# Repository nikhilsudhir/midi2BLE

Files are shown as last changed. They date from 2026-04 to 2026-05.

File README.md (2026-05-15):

<div align="center">

# midi2BLE

**Custom wireless MIDI adapter — ESP32-S3, LiPo powered, custom PCB**



[]()


A custom, battery-powered BLE MIDI adapter with a bespoke PCB and 3D-printed enclosure. Bridges a USB MIDI keyboard to a Mac over Bluetooth LE, eliminating the cable between instrument and computer.

[**View project page →**](https://nikhilsudhir.github.io/projects/midi2BT.html)

</div>

---

## Signal flow

<div align="center">

| **USB MIDI Keyboard** | | **ESP32-S3** | | **macOS** | | **DAW** |
|:---:|:---:|:---:|:---:|:---:|:---:|:---:|
| *(e.g. MPK Mini III)* | `── USB ──►` | *midi2BLE firmware* | `── BLE MIDI ──►` | *Audio MIDI Setup* | `──►` | *FL Studio* |

</div>

---

## Features

| | |
|---|---|
| **Wireless mode** | ESP32-S3 acts as USB host; MIDI data forwarded over BLE to macOS |
| **Passthrough mode** | Keyboard connected directly to upstream USB-C via hardware switch — ESP32 out of data path |
| **USB MIDI host** | Enumerates any class-compliant USB MIDI controller — no driver needed |
| **BLE MIDI peripheral** | Apple BLE MIDI spec, appears as a native MIDI port in Audio MIDI Setup |
| **MIDI panic** | On USB disconnect, sends Note Off + CC 123/120 for every active note on all 16 channels |
| **Auto-advertising** | Restarts BLE advertising automatically on every disconnect or reboot |
| **OLED display** | SPI-connected display shows mode, BLE status, battery %, and estimated runtime |
| **Battery management** | LiPo charge, power-path control, and ADC-based battery sense |

---

## Hardware

### Electronics

| Component | Part | Role |
|---|---|---|
| MCU / BLE | ESP32-S3-WROOM-1-N8 | Application processor, USB host, BLE MIDI |
| LiPo charger | BQ24079RGTT | 1-cell USB-C LiPo charging with power path |
| Buck regulator | TPS62162DSG | 3.3 V system rail |
| Boost converter | TLV61047DDC | 5 V VBUS supply for keyboard (wireless mode) |
| Power mux | TPS2116DRL | Battery / USB-C power-path switching |
| USB switch | TS3USB30EDGSR | Routes keyboard D+/D− to ESP32 or upstream port |
| USB ESD | PRTR5V0U2X | ESD protection on USB lines |
| Display | SPI OLED | Mode, connection status, battery info |

> Tested with an **Akai MPK Mini III**. Any USB class-compliant MIDI device should work.

### PCB

| | |
|---|---|
| Dimensions | 100 × 40 mm |
| Layers | 4 |
| Stackup | JLCPCB JLC04161H-7628 |
| Surface finish | HASL |
| Soldermask | Black |
| Mounting holes | M2.5 |

---

## Repository structure

- `main/` — Firmware (ESP-IDF / C) — see [main/README.md](main/README.md)
- `hardware/`
  - `ecad/` — KiCad schematic & PCB layout — see [hardware/ecad/README.md](hardware/ecad/README.md)
  - `mcad/` — Fusion 360 enclosure — see [hardware/mcad/README.md](hardware/mcad/README.md)
- `CMakeLists.txt`
- `sdkconfig.defaults`

---

## Build status

| Component | Status |
|---|---|
| Firmware | ✅ Complete |
| Schematic | ✅ Complete |
| PCB layout | ✅ Complete |
| Enclosure | ✅ Complete |

---

<div align="center">

[nikhilsudhir.github.io](https://nikhilsudhir.github.io/projects/midi2BLE.html)

</div>

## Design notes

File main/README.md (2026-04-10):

# Firmware

ESP32-S3 firmware for the midi2BLE adapter. Written in C using ESP-IDF v6.0 and NimBLE.

---

## Architecture

Three tasks run concurrently under FreeRTOS:

| Task | Priority | Description |
|---|---|---|
| `usb_host` | 2 | Runs the USB host library event loop |
| `class` | 3 | USB class driver — enumerates devices, handles MIDI transfers |
| NimBLE host | — | Managed internally by NimBLE port |

`app_main` initialises BLE, starts both tasks, then returns.

---

## File structure

```
main/
├── usb_host_lib_main.c     Entry point, USB host library task
├── class_driver.c          USB class driver, MIDI parsing, note tracking & panic
├── ble_midi.c              BLE MIDI peripheral, GATT service, advertising
├── ble_midi.h              Module interface
├── idf_component.yml       Component dependencies
└── CMakeLists.txt
```

---

## Module overview

### `usb_host_lib_main.c`
Entry point. Initialises the BLE MIDI peripheral, installs the USB host library, and spawns the USB host and class driver tasks.

### `class_driver.c`
Registers as a USB host client and waits for MIDI devices to connect. On connection it claims the MIDI Streaming interface and begins bulk IN transfers. Incoming 4-byte USB MIDI event packets are parsed, forwarded over BLE, and tracked for active note state. On disconnect, fires a MIDI panic before releasing the device.

### `ble_midi.c` / `ble_midi.h`
NimBLE peripheral implementing the Apple BLE MIDI spec. Exposes two functions:

```c
void ble_midi_init(void);
void ble_midi_send(const uint8_t *midi_bytes, int len);
```

Advertising starts automatically on boot and restarts on every disconnect.

---

## MIDI panic

If a USB MIDI device is unplugged while notes are held, the host would otherwise receive no Note Off and notes would drone indefinitely. On every USB disconnect the firmware:

1. Sends Note Off for every tracked active note
2. Sends CC 123 (All Notes Off) on all 16 channels
3. Sends CC 120 (All Sound Off) on all 16 channels

---

## Building

Requires [ESP-IDF v6.0](https://docs.espressif.com/projects/esp-idf/en/v6.0/esp32s3/get-started/).

```bash
idf.py build
idf.py -p PORT flash monitor
```

Target is fixed to `esp32s3` via `sdkconfig.defaults`.

---

## Dependencies

| Component | Source |
|---|---|
| `espressif/usb ^1.0.0` | [ESP-IDF Component Registry](https://components.espressif.com/components/espressif/usb) |
| NimBLE | Bundled with ESP-IDF (`CONFIG_BT_NIMBLE_ENABLED`) |

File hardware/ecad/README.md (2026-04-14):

# midi2BLE

## Overview

This device is a portable USB-to-BLE MIDI bridge designed to interface with USB MIDI controllers such as the Akai MPK Mini III.

It supports two user-selectable modes:

* Wireless BLE MIDI operation
* Wired USB passthrough operation

The device is battery powered with USB-C charging and includes an onboard OLED display for status and battery information.

---

## Operating Modes

### 1. Wireless Mode

In this mode, the device acts as a BLE MIDI bridge.

#### Behavior

* ESP32-S3 operates as a USB host
* MIDI data is read from the keyboard and transmitted via BLE
* Device is powered from internal LiPo battery
* OLED displays:

  * battery percentage
  * estimated runtime
  * BLE connection status
  * keyboard connection status

#### Power

* Battery supplies system power
* Optional charging via USB-C

---

### 2. Passthrough Mode

In this mode, the device behaves as a direct USB cable between the keyboard and a computer.

#### Behavior

* Keyboard is directly connected to upstream USB-C port via hardware switching
* ESP32 is not part of the USB data path
* BLE functionality is disabled
* OLED remains active and displays:

  * "WIRED MODE"
  * charging status
  * battery percentage

#### Power

* System is powered from upstream USB-C
* Battery does NOT power the system
* Battery may still be charged

---

## Mode Selection

* A physical switch selects between:

  * WIRELESS
  * WIRED
* The switch is authoritative
* Mode switching is NOT live
* Device must be restarted after changing modes

---

## Ports

### Upstream USB-C Port

* Used for:

  * charging the device
  * connecting to a computer in passthrough mode
* Supplies system power when connected

### Keyboard USB-C Port

* Used to connect the MIDI controller
* Behavior depends on mode:

  * Wireless: connected to ESP32 USB host
  * Passthrough: connected directly to upstream USB-C

---

## Power Architecture

* 1-cell LiPo battery
* USB-C charging input
* Power-path design allows:

  * operation while charging
  * seamless transition between power sources

### Power Priorities

#### Wireless Mode

1. Battery powers system
2. USB-C supplements or charges battery

#### Passthrough Mode

1. Upstream USB-C powers system
2. Battery is isolated from load
3. Battery may still charge

---

## USB Routing

### Wireless Mode

* Keyboard D+/D- connected to ESP32 USB host

### Passthrough Mode

* Keyboard D+/D- connected directly to upstream USB-C port

This is implemented using a USB 2.0 switch/multiplexer.

---

## Keyboard Power (VBUS)

### Wireless Mode

* Supplied by internal 5V boost converter

### Passthrough Mode

* Supplied directly from upstream USB-C VBUS

---

## Display (OLED)

* SPI-connected monochrome OLED display
* Displays:

  * battery percentage
  * estimated runtime
  * current mode
  * connection status

---

## Firmware Behavior

### Wireless Mode

* USB host enabled
* BLE MIDI enabled
* MIDI data forwarded USB → BLE

### Passthrough Mode

* USB host disabled
* BLE disabled
* ESP32 used only for UI/status

---

## V1 Scope

### Included

* BLE MIDI output
* USB passthrough
* battery operation
* USB-C charging
* OLED display
* manual mode switch

### Excluded

* custom RF protocols
* MIDI remapping
* display UI complexity
* automatic mode switching
* USB hub functionality

---

## Hardware Design

The schematic and PCB layout are both complete. The design is implemented in **KiCad 10.0**.

| | |
|---|---|
| Revision | 1 |
| Schematic date | 2026-04-11 |
| PCB date | 2026-04-12 |

The schematic is split across seven sheets:

| Sheet | Description |
|---|---|
| Root | Top-level block diagram and inter-sheet connections |
| Power | LiPo charging, buck/boost regulation, and power-path control |
| ESP32_S3 | ESP32-S3-WROOM-1 module, decoupling, and GPIO assignments |
| USB Data | USB 2.0 data switching between keyboard and upstream port |
| VBUS Switching | 5V VBUS supply selection for the keyboard port |
| OLED UI | SPI OLED display and mode select switch |
| Battery Sense | Resistor divider and ADC input for battery voltage measurement |

### Key ICs

| IC | Part | Function |
|---|---|---|
| U1 | ESP32-S3-WROOM-1 | Main MCU + Wi-Fi/BLE module |
| U2 | BQ24074RGTT | 1-cell LiPo charger |
| U3 | TPS62162DSG | 3.3 V synchronous buck regulator |
| U4 | TLV61047DDC | 5 V boost converter (keyboard VBUS in wireless mode) |
| U5 | TPS2116DRL | Dual-input power mux (battery vs. USB-C power path) |
| U6 | TS3USB30EDGSR | USB 2.0 high-speed switch (keyboard data routing) |
| U7 | PRTR5V0U2X | USB ESD protection |

### PCB

The PCB is laid out in KiCad. All components are placed and fully routed.

**Board dimensions:** 75 × 40mm  
**Thickness:** 1.6mm  
**Layers:** 4  

#### Stackup

| Layer | Type | Thickness | Material |
|---|---|---|---|
| F.Cu | Signal | 35µm | Copper |
| Dielectric 1 | Prepreg | 0.1mm | FR4 |
| In1.Cu | GND plane | 35µm | Copper |
| Dielectric 2 | Core | 1.24mm | FR4 |
| In2.Cu | 3.3V power plane | 35µm | Copper |
| Dielectric 3 | Prepreg | 0.1mm | FR4 |
| B.Cu | Signal | 35µm | Copper |

Inner layers are solid copper fills: In1 = GND, In2 = SYS_3V3.

**Test points:** TP1–TP6  
**Via size:** 0.45mm diameter, 0.2mm drill

---

## Summary

This V1 design prioritizes:

* simplicity
* reliability
* clear user control

The system uses a manual mode switch and hardware-level USB routing to ensure predictable behavior and robust operation.

**Current status:** Schematic and PCB layout complete. Ready for fabrication review.

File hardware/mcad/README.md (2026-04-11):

# MCAD — Enclosure Design

3D-printed enclosure for the midi2BLE hardware.

## Status

| Part | Status |
|---|---|
| Enclosure body | ✅ v1 designed, fitment tested against keyboard |
| USB-B cutout | ✅ Cutout included in v1 for keyboard USB-B port |
| Lid / cover | 🔧 Pending |
| PCB internal pocket | 🔧 Pending PCB dimensions from ECAD |

## Contents

- Enclosure body v1 — USB-B cutout, designed around reference keyboard model for fitment
- Lid / cover *(pending)*
- STL files for printing *(pending)*
- STEP files for reference *(pending)*

## Tools

- Fusion 360

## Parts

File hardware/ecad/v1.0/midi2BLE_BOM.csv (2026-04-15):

Id | Designator | Footprint | Quantity | Designation | Supplier and ref
1 | C1, C2, C3, C4, C10, C18 | C_0603_1608Metric | 6 | 10uF
2 | C5, C6, C7, C8, C9, C11, C12, C13, C14, C15, C16, C17, C19 | C_0402_1005Metric | 13 | 100nF
3 | D1, D2 | SOT-143 | 2 | PRTR5V0U2X
4 | J1 | USB_C_Receptacle_Amphenol_12401610E4-2A_CircularHoles | 1 | USB_C_Receptacle
5 | J2 | JST_PH_B2B-PH-K_1x02_P2.00mm_Vertical | 1 | Conn_01x02
6 | J4 | JST_EH_B7B-EH-A_1x07_P2.50mm_Vertical | 1 | Conn_01x07
7 | J6 | JST_PH_B4B-PH-K_1x04_P2.00mm_Vertical | 1 | Conn_01x04
8 | L1, L2 | L_1008_2520Metric | 2 | 2.2uH
9 | R1, R2 | C_0402_1005Metric | 2 | 5.1k
10 | R3 | C_0402_1005Metric | 1 | 590
11 | R4 | C_0402_1005Metric | 1 | 1k
12 | R5, R6, R7, R8, R9 | C_0402_1005Metric | 5 | 10k
13 | R10 | C_0402_1005Metric | 1 | 100
14 | R11 | C_0402_1005Metric | 1 | 220k
15 | R12, R13, R14 | C_0402_1005Metric | 3 | 100k
16 | SW1, SW2 | SW_SPST_B3U-1000P | 2 | SW_Push
17 | SW3 | SW_Slide_SPDT_Angled_CK_OS102011MA1Q | 1 | SW_SPDT
19 | U1 | VQFN-16-1EP_3x3mm_P0.5mm_EP1.68x1.68mm_ThermalVias | 1 | BQ24079RGTT
20 | U2 | WSON-8-1EP_2x2mm_P0.5mm_EP0.9x1.6mm_ThermalVias | 1 | TPS62162DSG
21 | U3 | SOT-23-5 | 1 | TLV61047DDC
22 | U4 | ESP32-S3-WROOM-1 | 1 | ESP32-S3-WROOM-1
23 | U5 | SOT-583-8 | 1 | TPS2116DRL
24 | U6 | TSSOP-10_3x3mm_P0.5mm | 1 | TS3USB30EDGSR

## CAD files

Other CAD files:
hardware/mcad/midi2BLE.f3d

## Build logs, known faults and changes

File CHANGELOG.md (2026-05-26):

# Changelog

All notable changes to this project are documented here.

---

## [Unreleased]

---

## [2.0.0] — 05/2026

### Changed — Power Section

#### U1 — Battery Charger
- Replaced BQ24079RGTT with BQ24075RGT
- Fixes SYSOFF floating issue — BQ24075 does not have a SYSOFF pin

#### U3 — 5V Boost Converter
- Replaced TLV61047DDC with MT3608 (SOT-23-6) + external SS14 Schottky diode
- FB divider: R_upper = 68kΩ, R_lower = 8.2kΩ → 5.0V output
- EN pin driven by MODE_SEL GPIO — boost disabled in passthrough mode

#### U2 — 3.3V Buck Regulator (TPS62162DSG, unchanged IC)
- EN fix: previously tied to U3 VIN causing circular startup dependency; now connected directly to U1_OUT
- FB fix: previously connected to SYS_3V3 (wrong); now tied to GND

#### Miscellaneous Power
- R5 removed — 10kΩ VBUS_IN to GND bleed resistor served no purpose

### Changed — USB Switching (U6 TS3USB30E, unchanged IC)
- OE pin: previously driven by MODE_SEL (disconnected switch in one mode); now tied directly to GND (switch always enabled)

### Changed — ESP32 GPIO Assignments
- OLED SPI reassigned from GPIO11/12 → GPIO35/36 (GPIO11/12 conflict with octal flash on N8R2 variant)
- MODE_SEL reassigned from GPIO0 → GPIO2 (GPIO0 is boot strapping pin)

---

## [1.0.0] — 04/2026

### Known Issues (reason for v2 redesign)
- SYSOFF pin on BQ24079 left floating — internally pulled HIGH through 5MΩ to VBAT, disabling battery output and charging entirely; board appeared completely dead
- U2 EN tied to U3 VIN causing circular startup dependency
- U2 FB incorrectly connected to SYS_3V3 instead of GND
- U6 OE driven by MODE_SEL instead of tied to GND, disconnecting USB switch in one mode
- OLED SPI on GPIO11/12 conflicting with octal flash on ESP32-S3-WROOM-1-N8R2
- MODE_SEL on GPIO0 (boot strapping pin) causing boot issues

### Added

#### ECAD
- 7-sheet KiCad schematic — ERC clean
- Full 4-layer PCB routing complete — DRC clean
- Board: 100×40mm, JLCPCB JLC04161H-7628 stackup
- Surface finish: HASL, black soldermask
- Mounting holes: M2.5

#### MCAD
- Enclosure body v1 designed in Fusion 360 — USB-C cutout for keyboard port, fitment verified against reference keyboard model
- Rudimentary reference keyboard model created to assist with clearance and alignment

---

## [0.4.1] — 04/2026

### Added
- Full USB device name on screen — reads both manufacturer and product strings from USB descriptor, word-wraps to second line if longer than 21 characters
- Battery monitor code complete — ADC oneshot on GPIO4 with curve/line fitting calibration, battery bar and percentage on display; pending physical wiring (100kΩ resistors)

### Fixed
- Display driver rewritten for SH1106 compatibility — switched from horizontal addressing mode (SSD1306 only) to page-by-page writes which work on both SH1106 and SSD1306
- Charge pump command corrected for SH1106 (0xAD, 0x8B)
- Mode switch moved from GPIO0 to GPIO2 to avoid conflict with ESP32-S3 boot pin
- Build errors resolved — wrong USB host function name (`usb_host_device_info`), unused static function ordering

### Changed
- Display rotated 180° via segment remap and COM scan direction commands
- All screen text centred

---

## [0.4.0] — 04/2026

### Added
- GPIO mode switch — HIGH = WIRELESS (BLE), LOW = PASSTHROUGH (wired); reads at boot with internal pull-up
- Mode change detection via NVS — shows restart screen and reboots cleanly when switch position changes
- SH1106 SPI OLED display driver (128×64) with built-in 5×7 bitmap font
- Status screens for both modes — BLE connection state, USB device name, MIDI activity indicator
- USB product and manufacturer strings read from device descriptor and shown on screen
- 1 Hz OLED update task
- `mode_manager`, `oled_display`, and `battery` modules added as separate files

### Changed
- NVS initialisation moved to `app_main` so all modules share one init
- `app_main` branches on mode — PASSTHROUGH skips BLE and USB host entirely

---

## [0.3.0] — 04/2026

### Added
- MIDI panic on USB disconnect — sends Note Off for all active notes, plus CC 123 (All Notes Off) and CC 120 (All Sound Off) on all 16 channels
- Active note tracking per channel to avoid duplicate Note Off messages
- BLE advertising restarts automatically on every disconnect

### Changed
- Cleaned up repository structure — removed devcontainer, tidied .gitignore, added LICENSE and README

---

## [0.2.0] — 04/2026

### Added
- Full BLE MIDI peripheral implementation (Apple BLE MIDI spec)
- NimBLE GATT service with correct service and characteristic UUIDs
- MIDI forwarding from USB to BLE with proper timestamp framing
- Akai MPK Mini III confirmed working end-to-end

---

## [0.1.0] — 03/2026

### Added
- ESP32-S3 running as USB MIDI host
- USB MIDI device enumeration and MIDI Streaming interface detection
- Raw MIDI data passthrough to serial monitor for verification

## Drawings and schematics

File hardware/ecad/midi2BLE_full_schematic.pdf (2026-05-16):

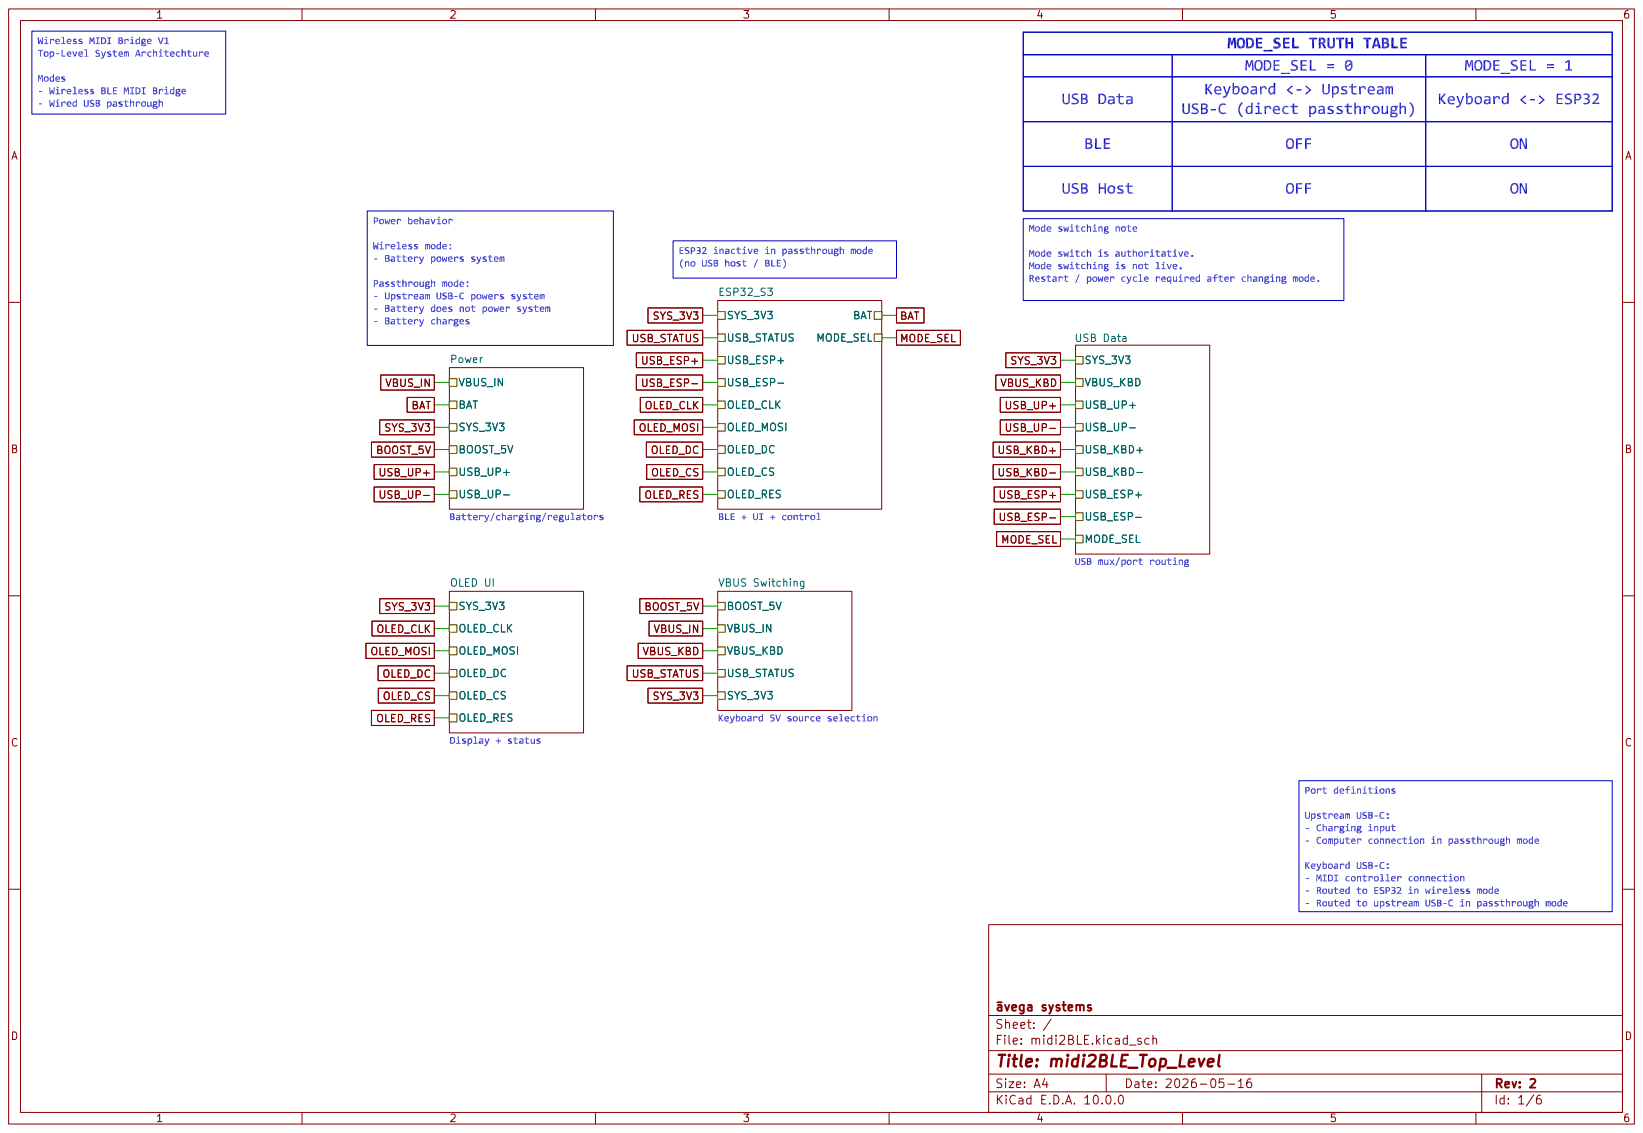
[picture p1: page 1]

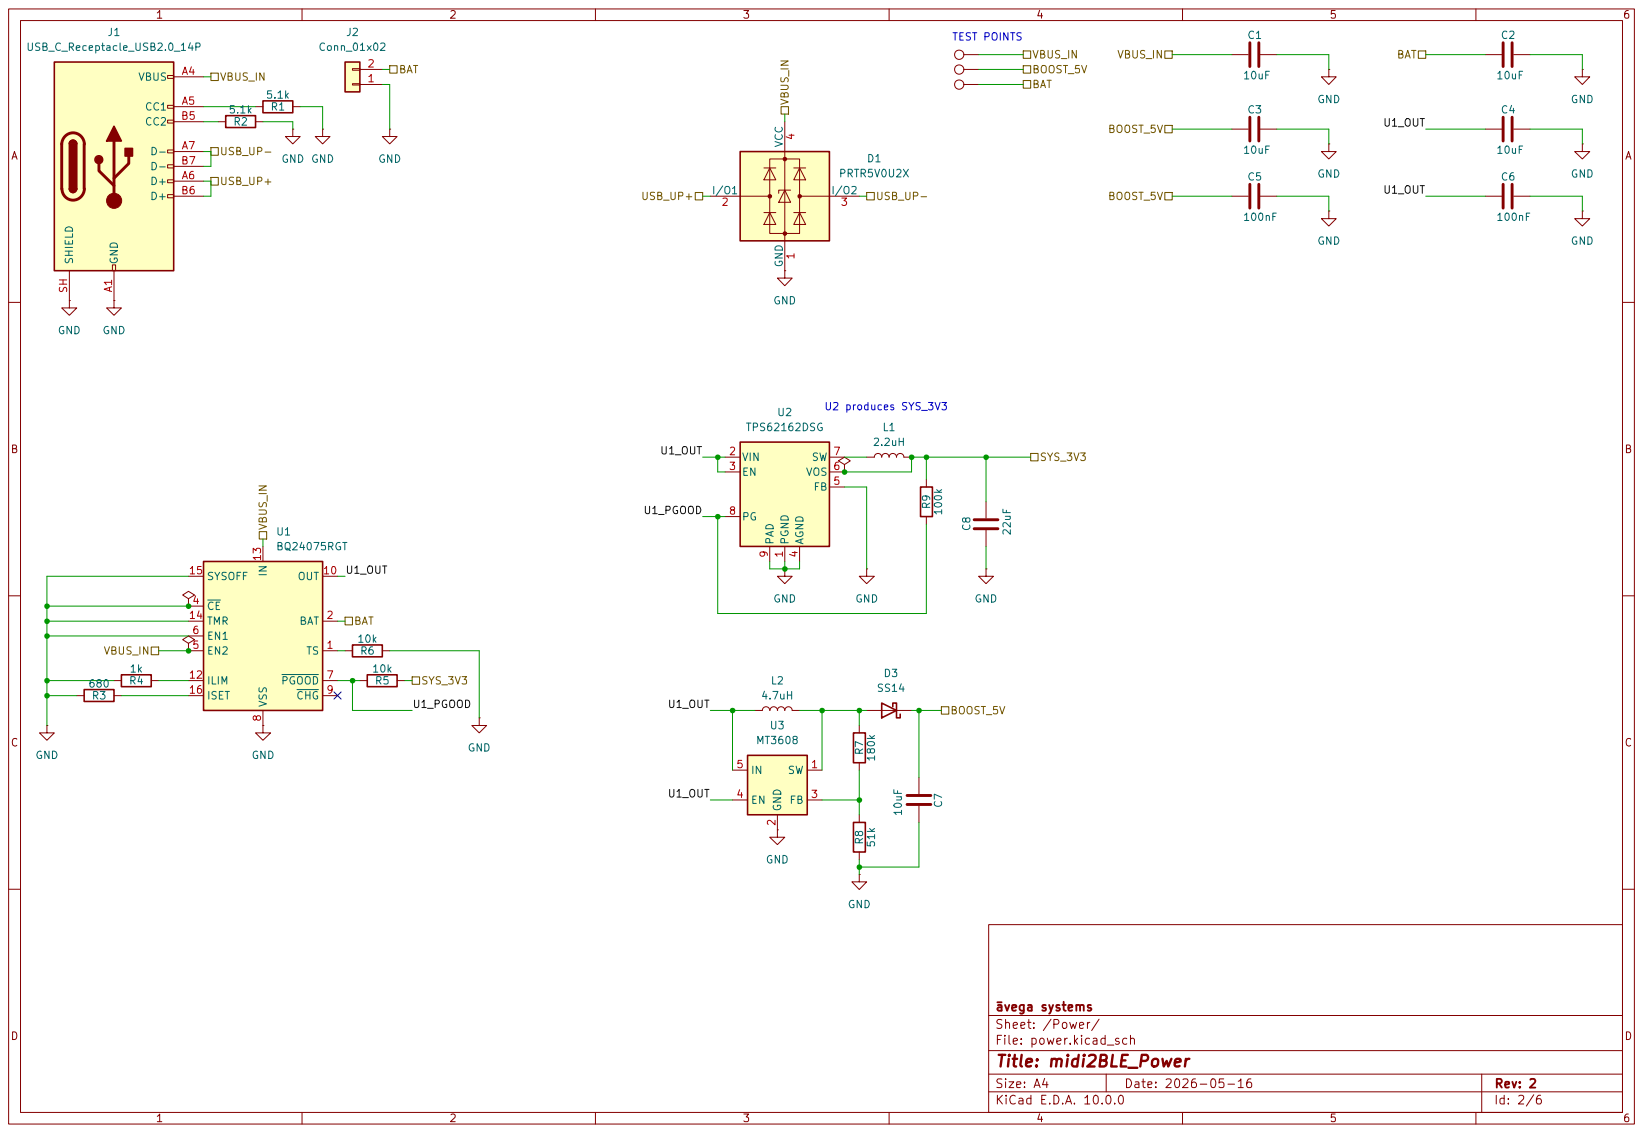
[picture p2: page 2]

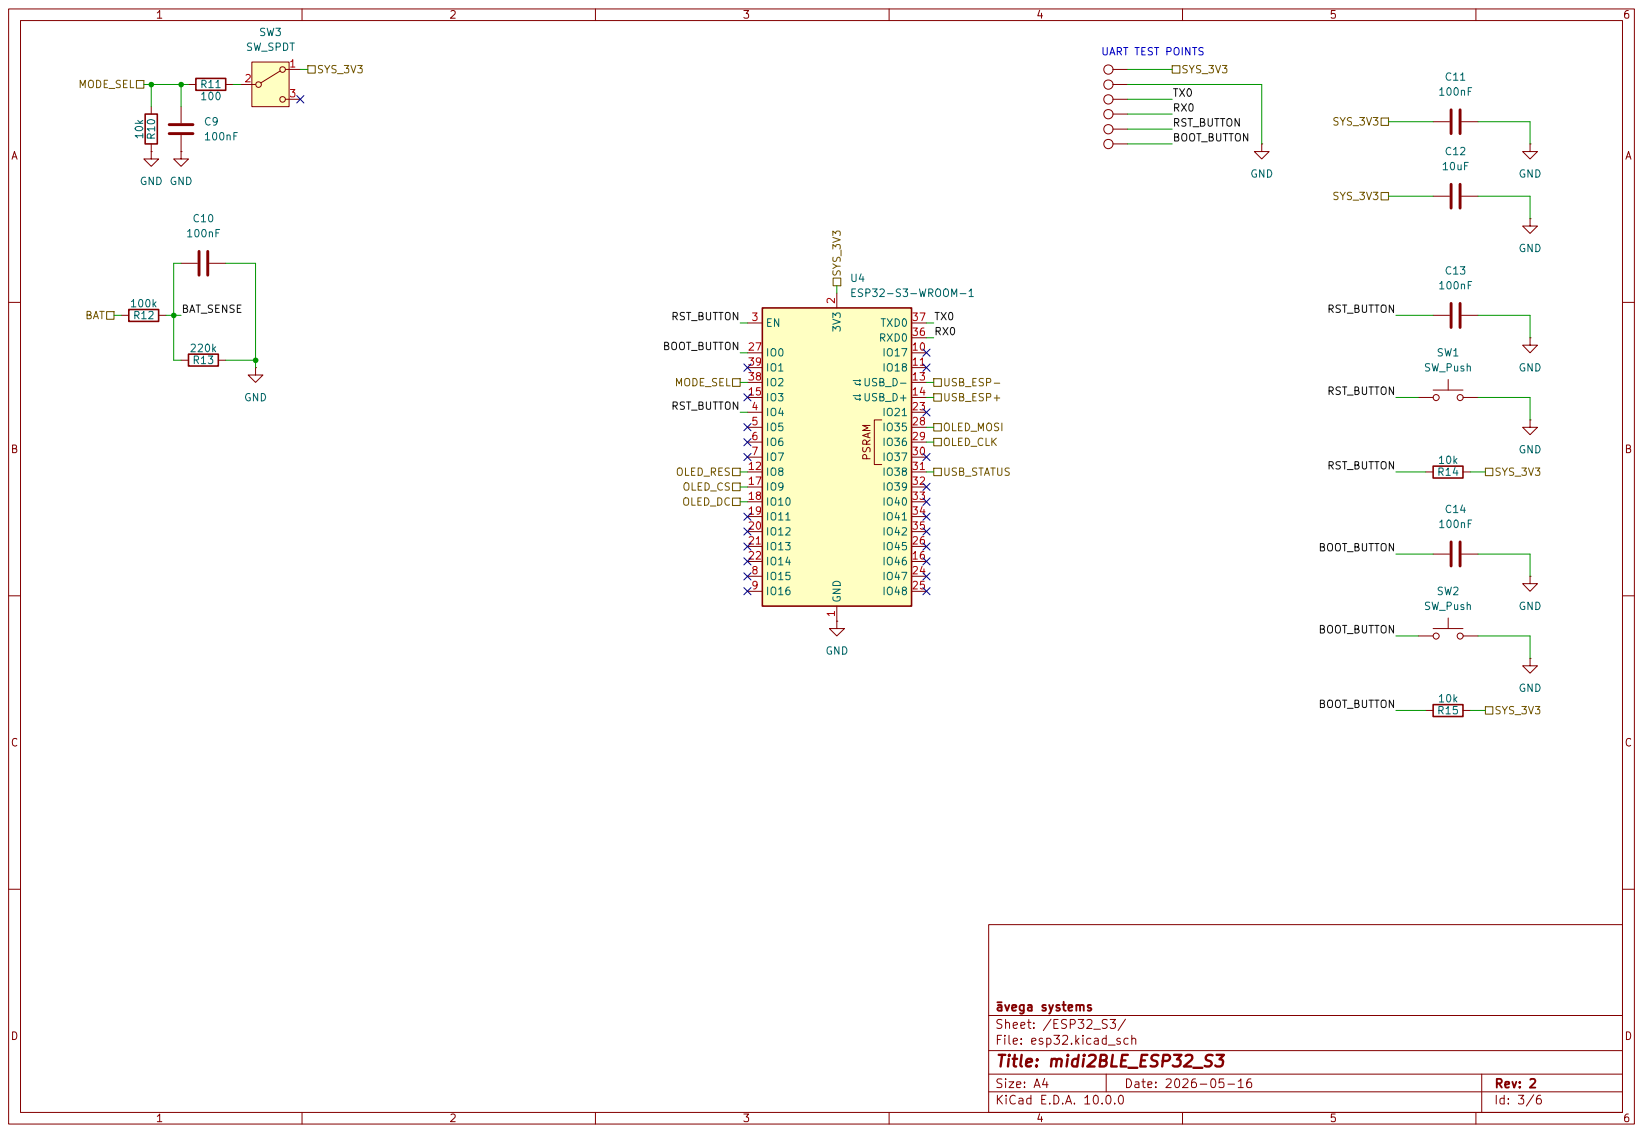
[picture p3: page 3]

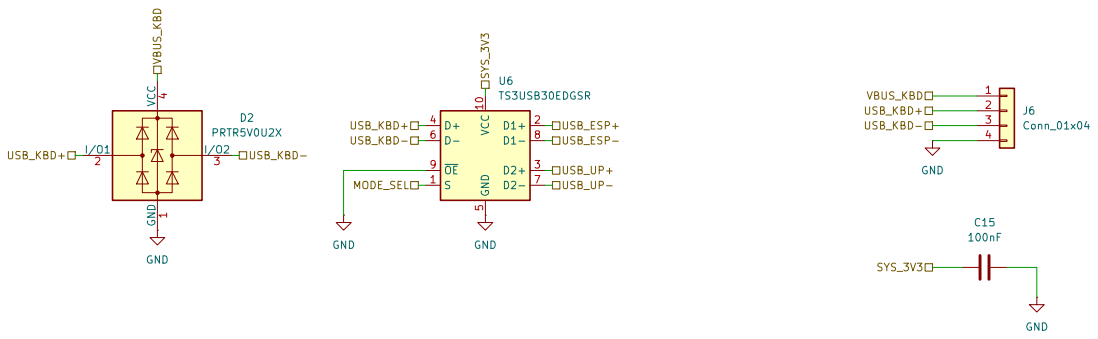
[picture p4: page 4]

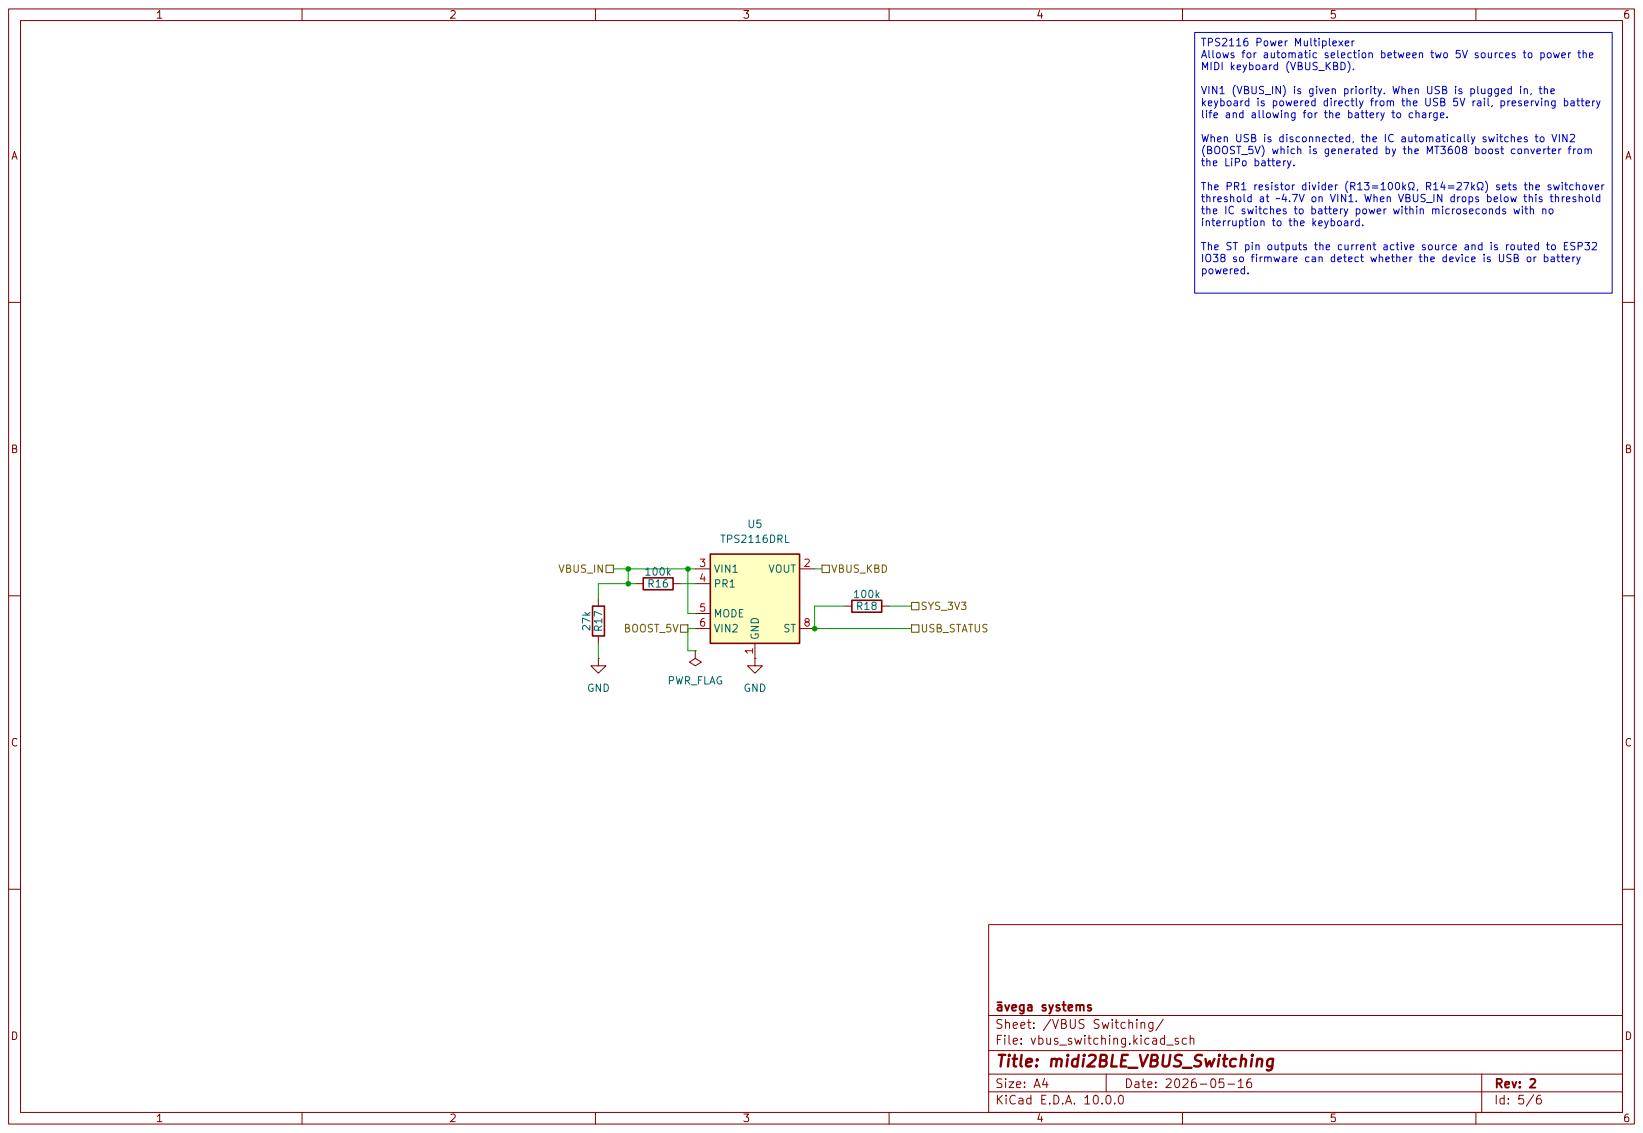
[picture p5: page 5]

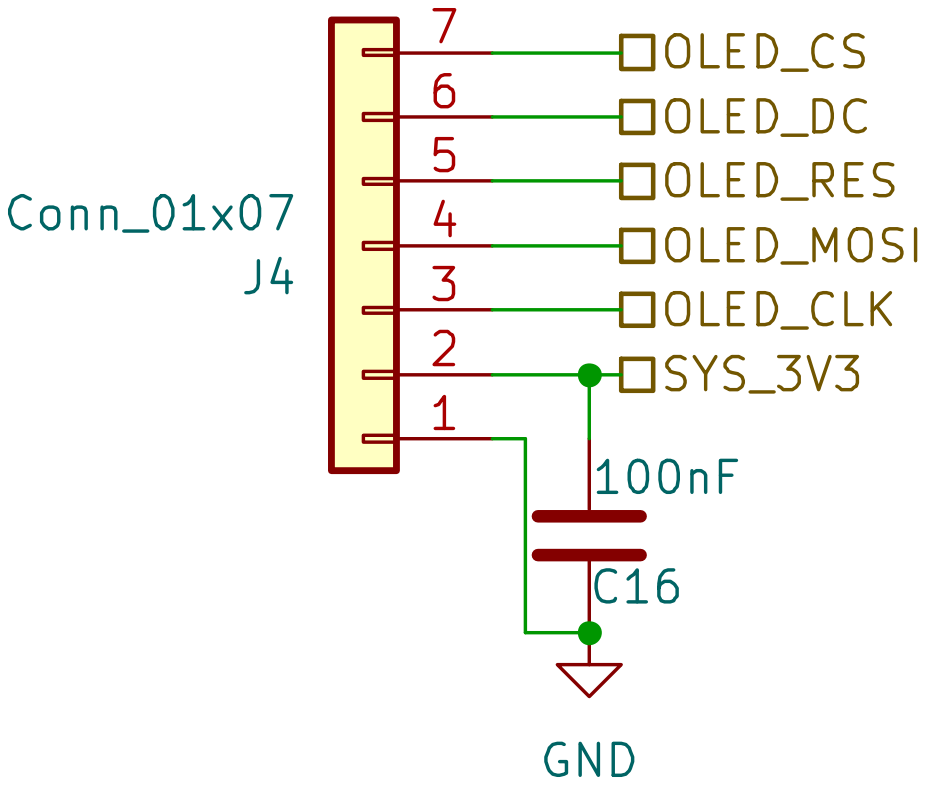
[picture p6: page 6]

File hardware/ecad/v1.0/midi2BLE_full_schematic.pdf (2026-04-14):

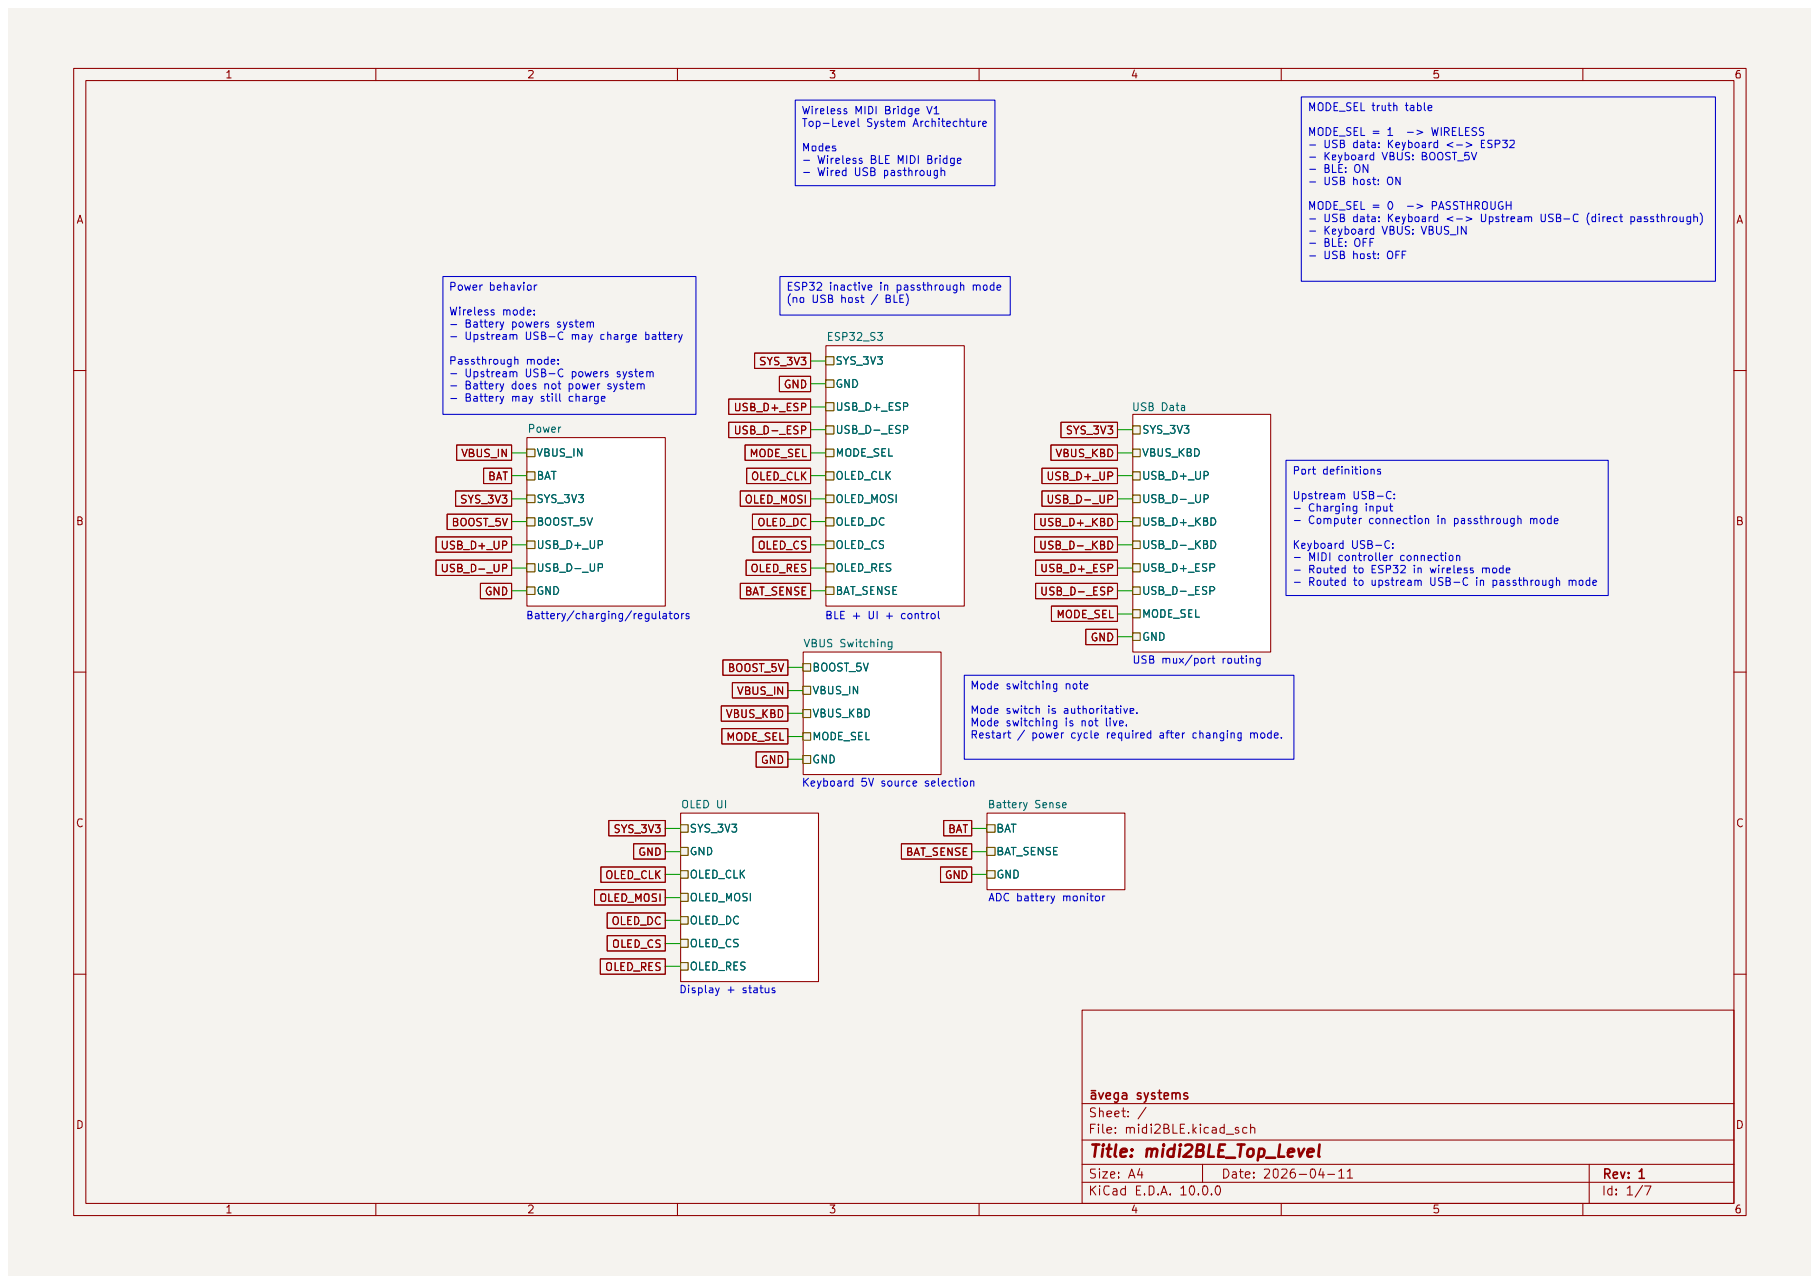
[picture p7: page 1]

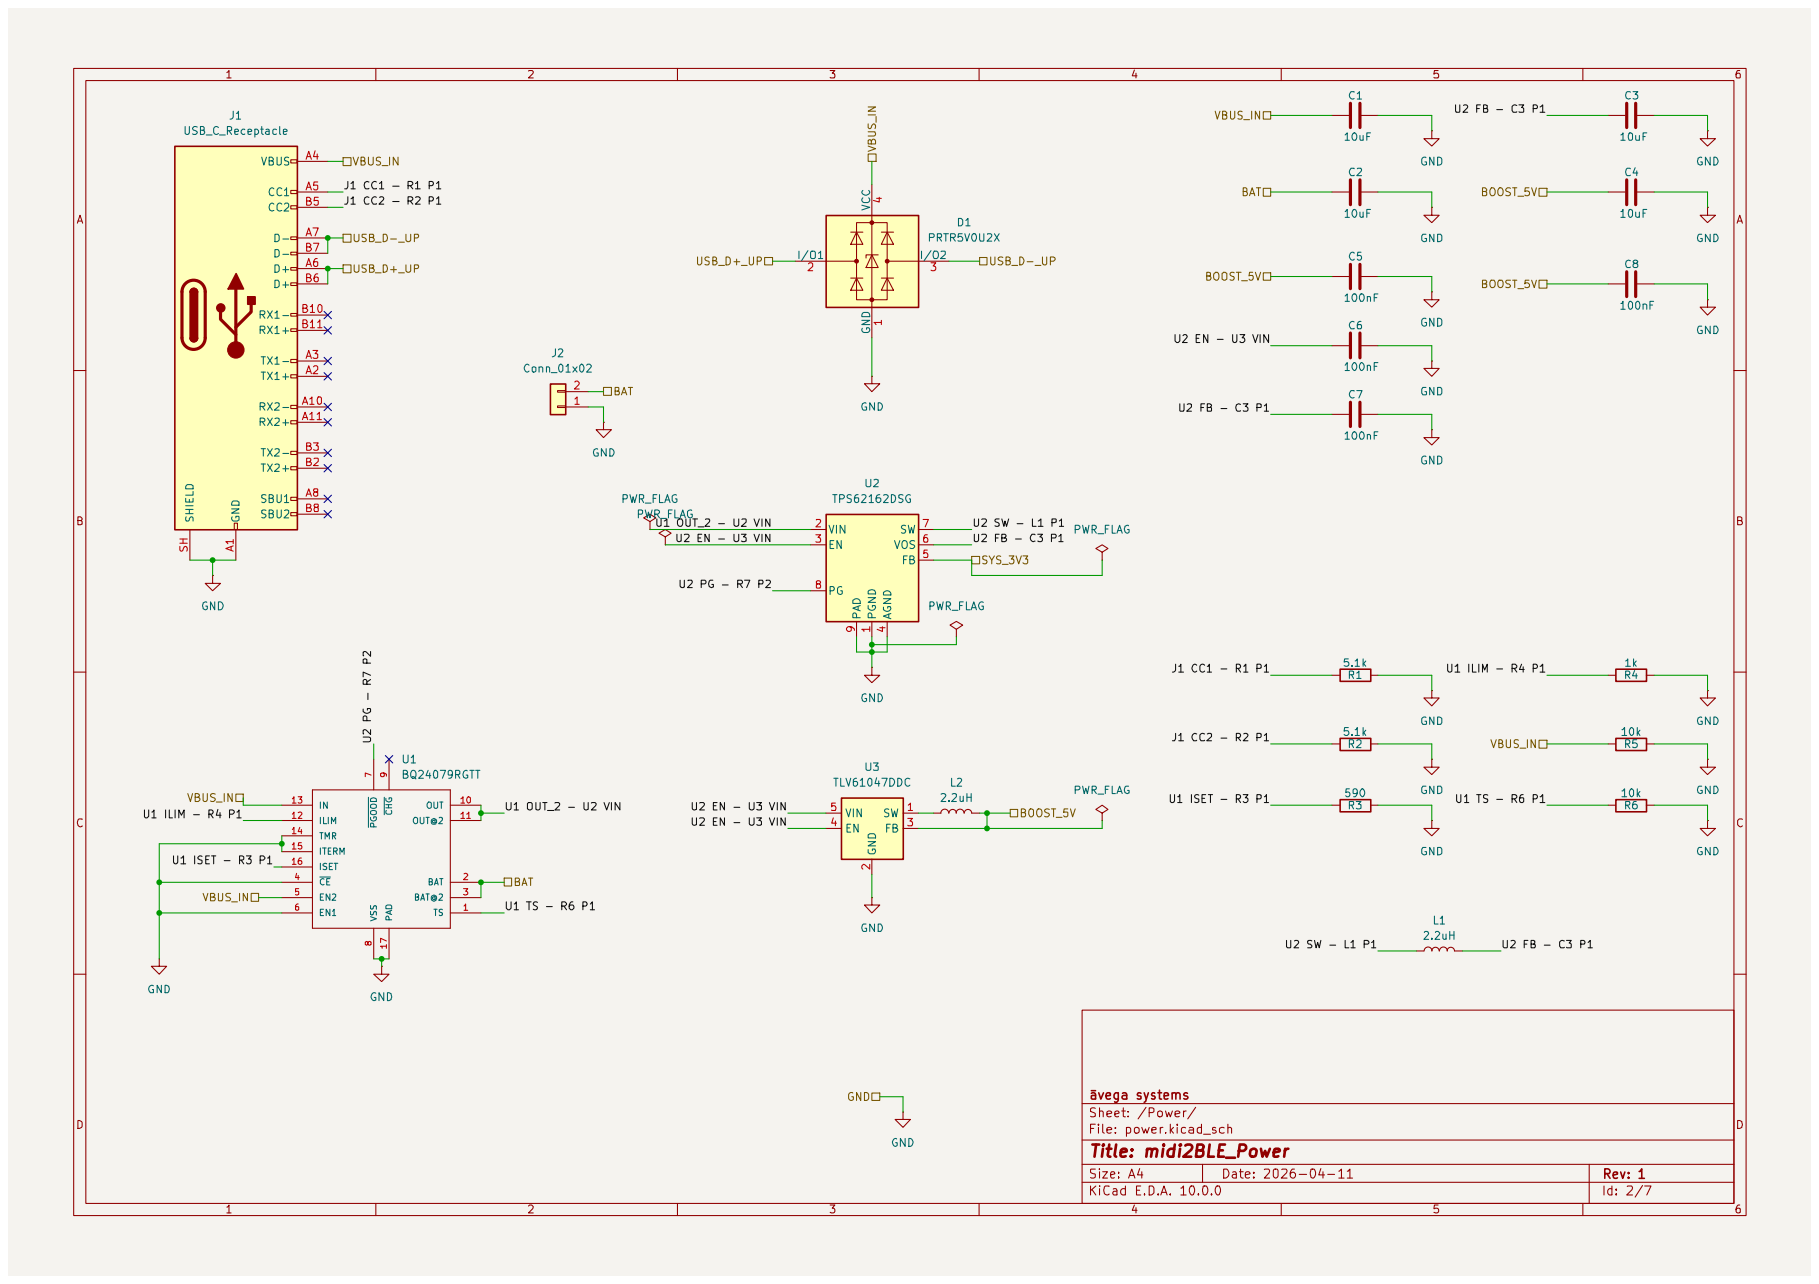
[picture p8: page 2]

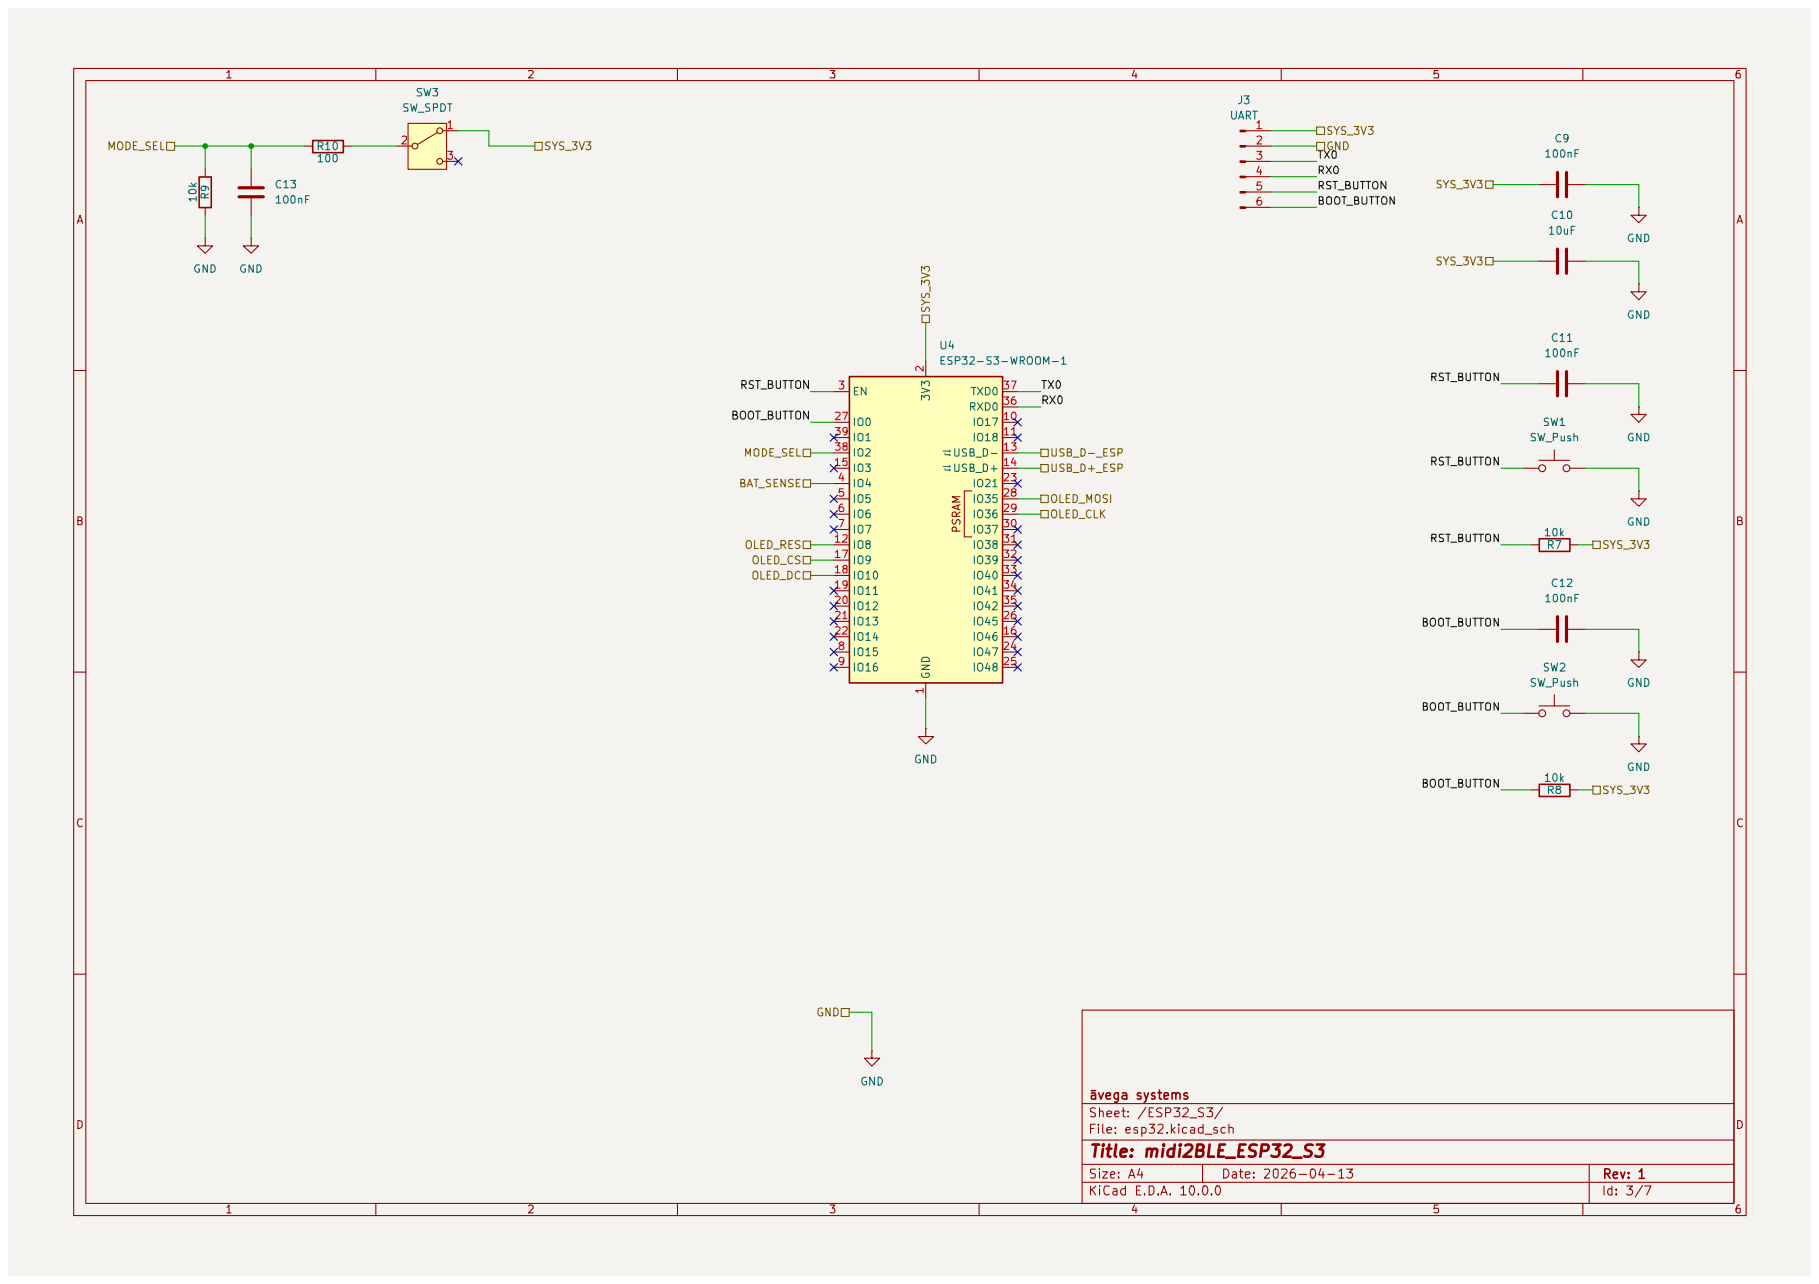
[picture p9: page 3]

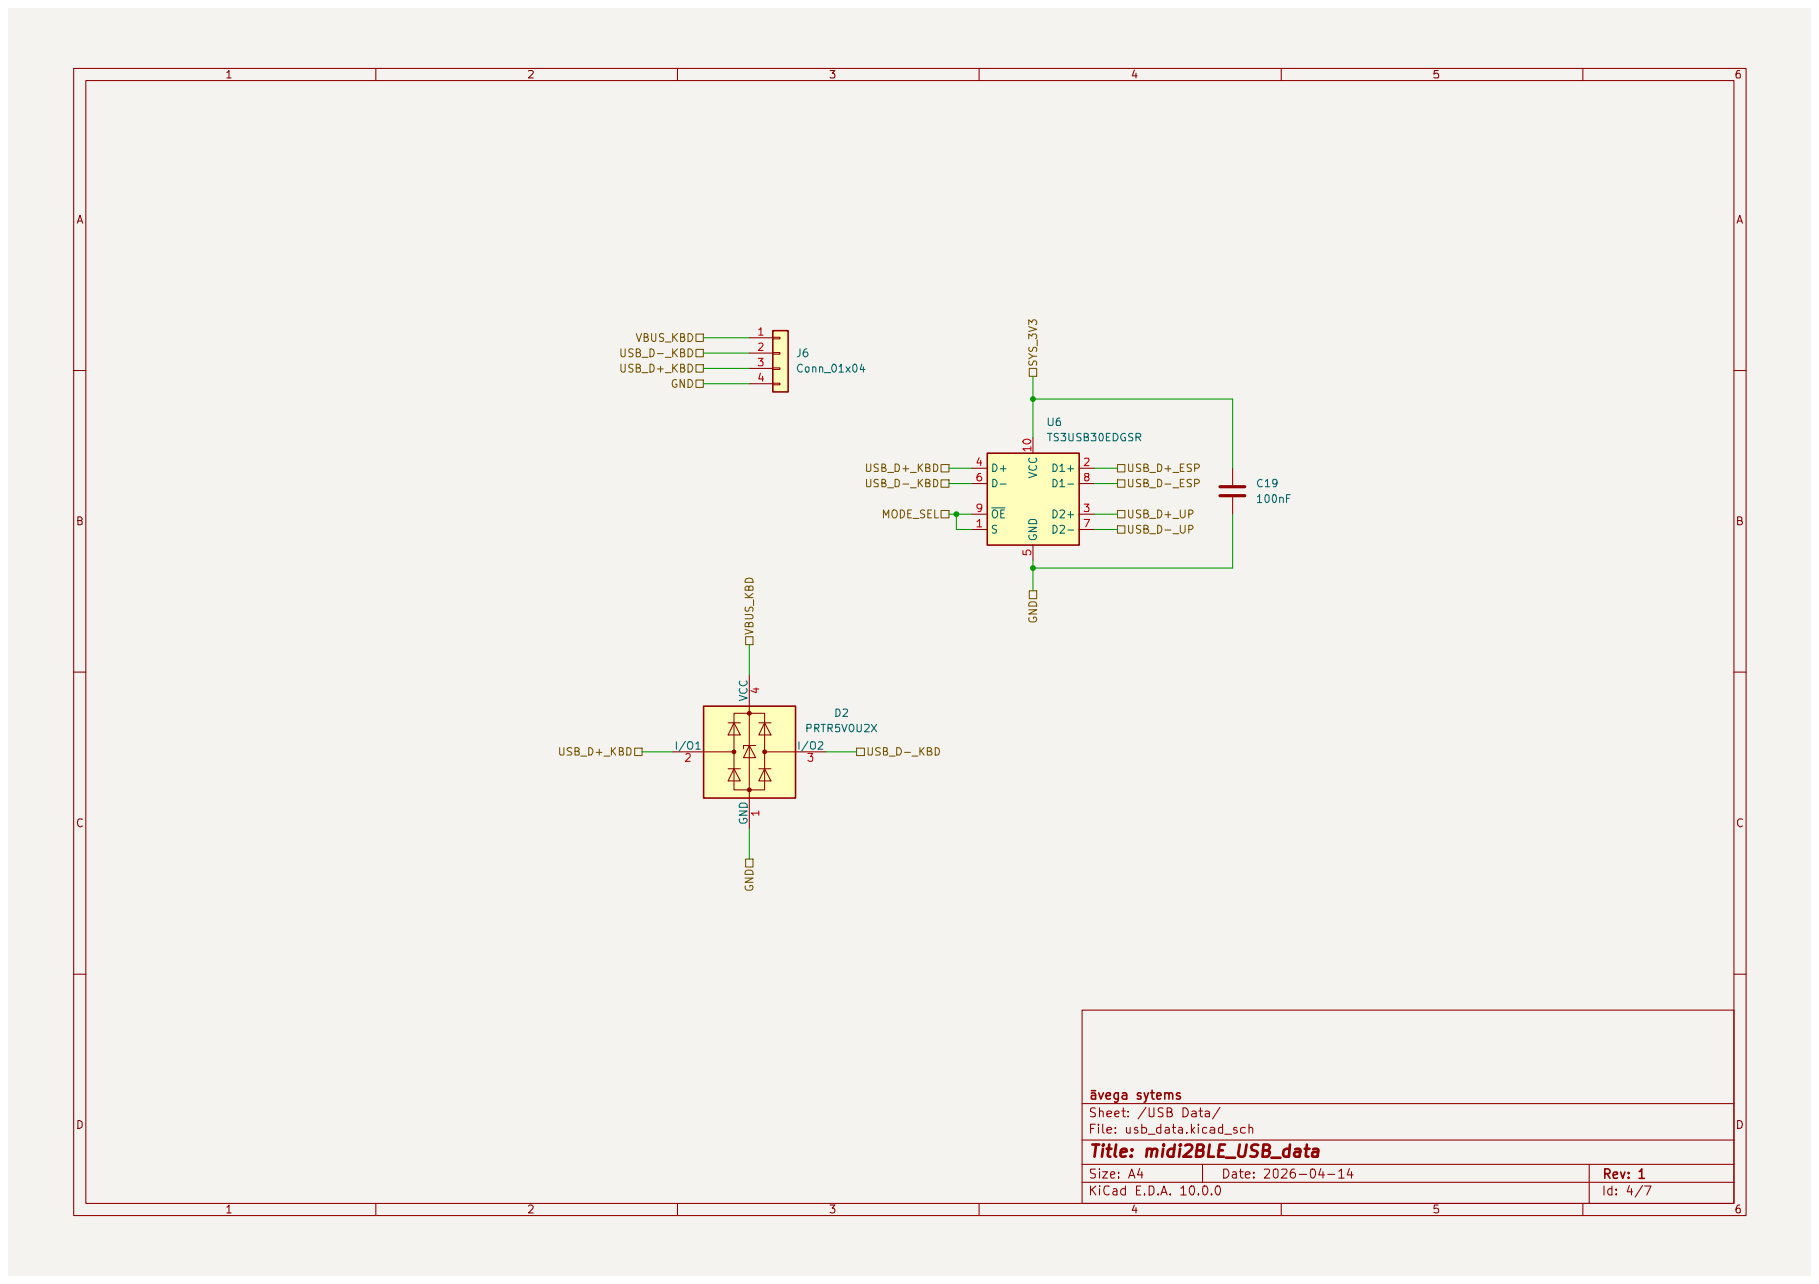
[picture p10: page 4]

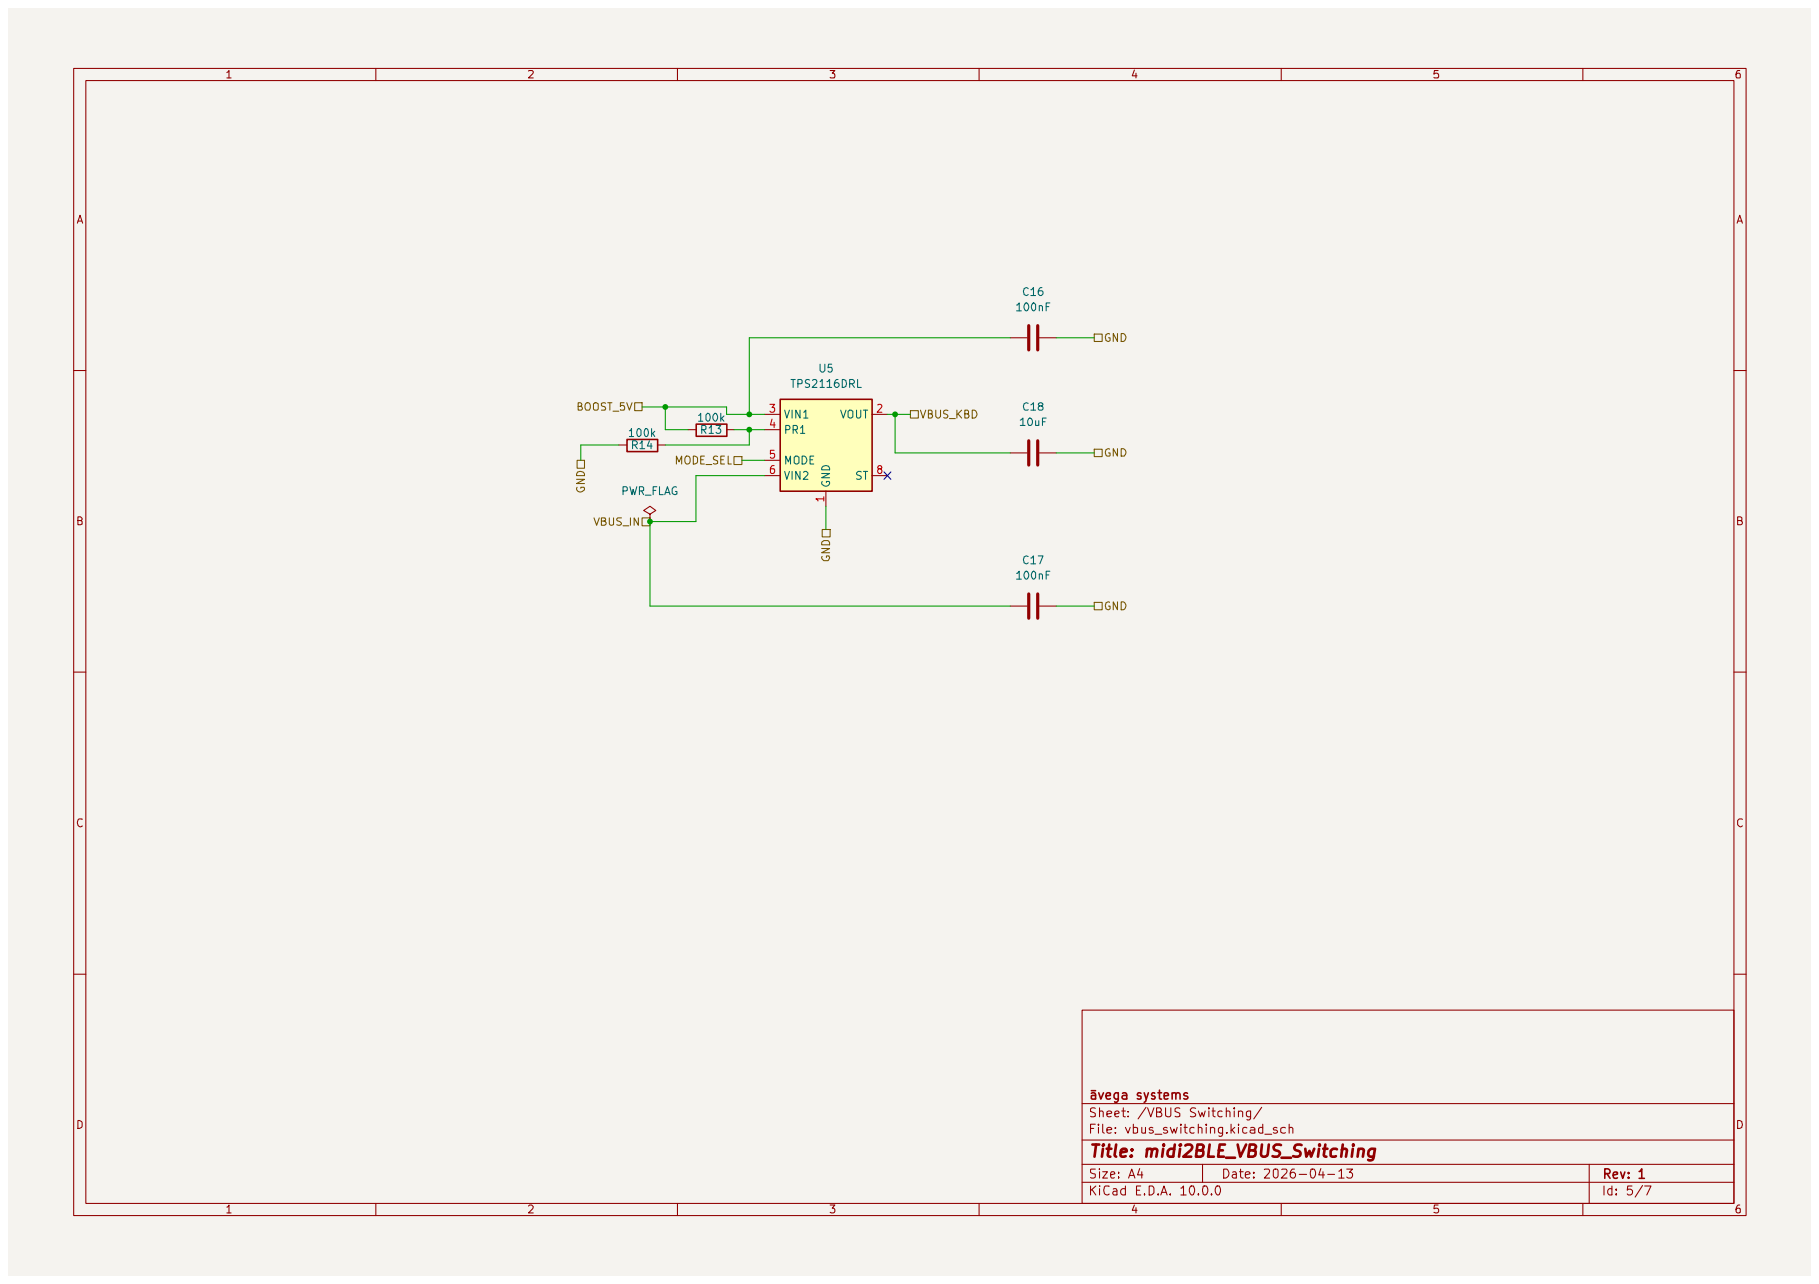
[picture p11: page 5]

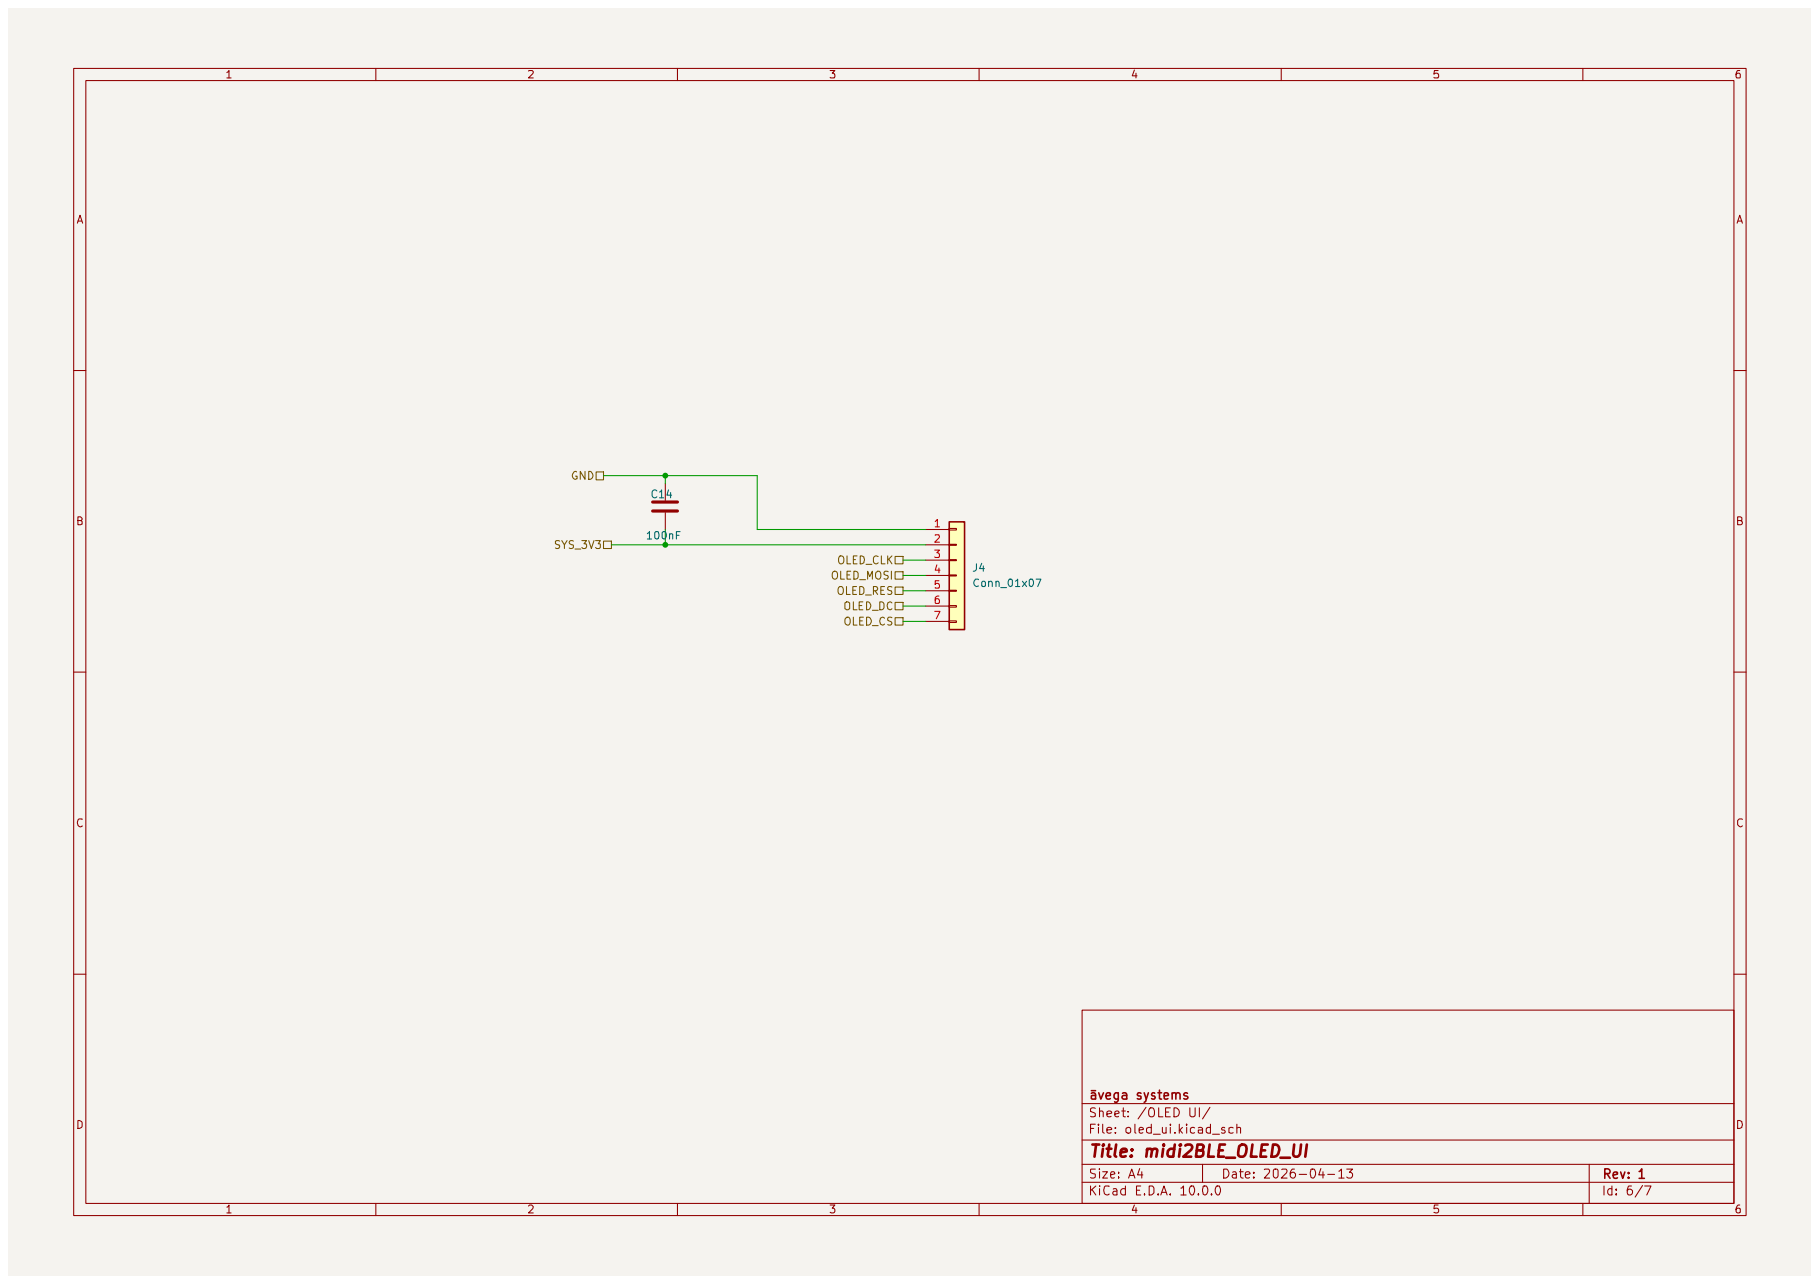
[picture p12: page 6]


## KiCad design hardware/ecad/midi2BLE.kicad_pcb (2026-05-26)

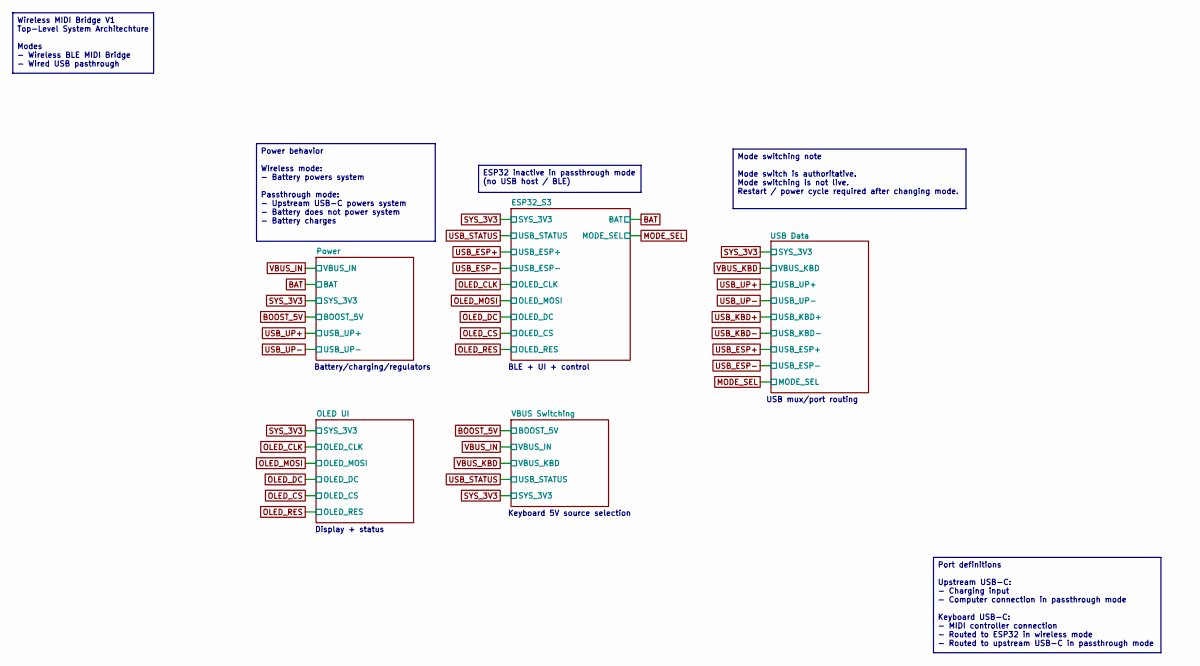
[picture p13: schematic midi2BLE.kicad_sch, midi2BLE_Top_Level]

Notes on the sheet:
Battery/charging/regulators
Keyboard 5V source selection
USB mux/port routing
Display + status
BLE + UI + control
Wireless MIDI Bridge V1 Top-Level System Architechture Modes - Wireless BLE MIDI Bridge - Wired USB pasthrough
Port definitions Upstream USB-C: - Charging input - Computer connection in passthrough mode Keyboard USB-C: - MIDI controller connection - Routed to ESP32 in wireless mode - Routed to upstream USB-C in passthrough mode
Mode switching note Mode switch is authoritative. Mode switching is not live. Restart / power cycle required after changing mode.
Power behavior Wireless mode: - Battery powers system Passthrough mode: - Upstream USB-C powers system - Battery does not power system - Battery charges
ESP32 inactive in passthrough mode (no USB host / BLE)

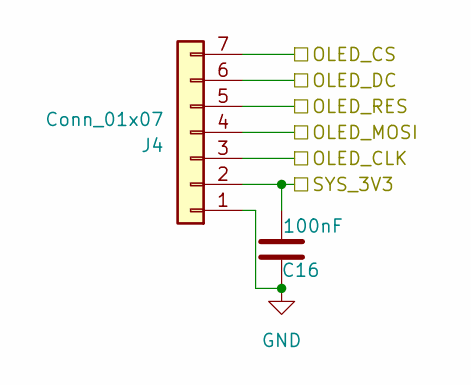
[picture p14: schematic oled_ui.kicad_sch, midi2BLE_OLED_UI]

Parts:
C16: 100nF; C_0603_1608Metric
J4: Conn_01x07; JST_EH_B7B-EH-A_1x07_P2.50mm_Vertical

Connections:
GND: C16.2, J4.1; also elsewhere on the board
OLED_CLK: J4.3; also elsewhere on the board
OLED_CS: J4.7; also elsewhere on the board
OLED_DC: J4.6; also elsewhere on the board
OLED_MOSI: J4.4; also elsewhere on the board
OLED_RES: J4.5; also elsewhere on the board
SYS_3V3: C16.1, J4.2; also elsewhere on the board

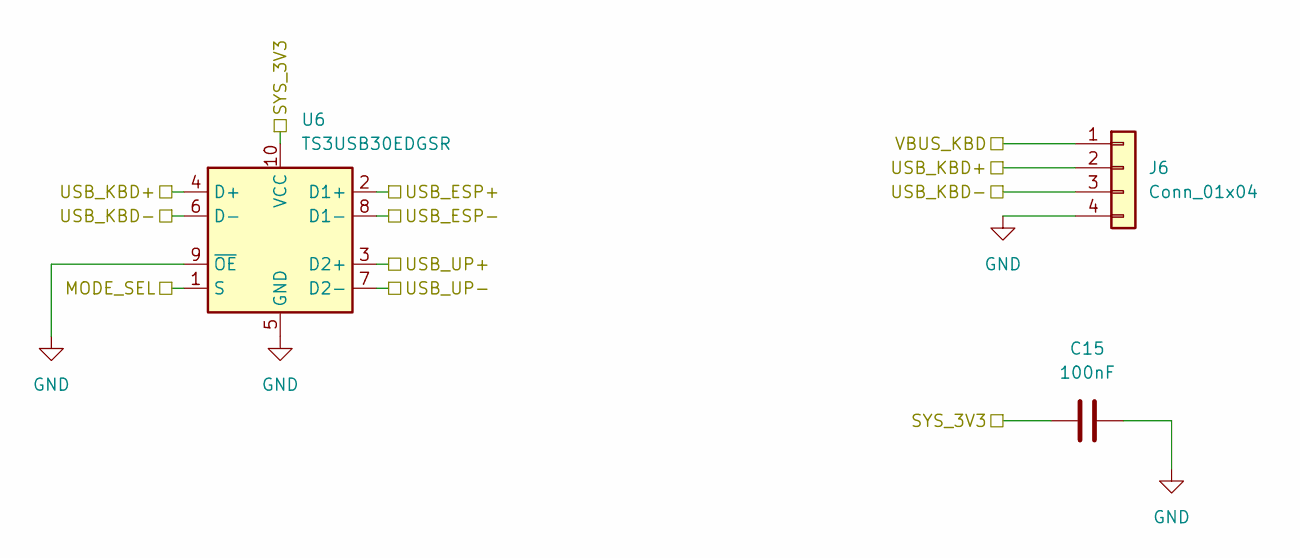
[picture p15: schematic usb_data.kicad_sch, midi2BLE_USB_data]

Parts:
C15: 100nF; C_0603_1608Metric
J6: Conn_01x04; JST_PH_B4B-PH-K_1x04_P2.00mm_Vertical
U6: TS3USB30EDGSR; TSSOP-10_3x3mm_P0.5mm

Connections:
GND: C15.1, J6.4, U6.5 (GND), U6.9 (~OE); also elsewhere on the board
MODE_SEL: U6.1 (S); also elsewhere on the board
SYS_3V3: C15.2, U6.10 (VCC); also elsewhere on the board
USB_ESP+: U6.2 (D1+); also elsewhere on the board
USB_ESP-: U6.8 (D1-); also elsewhere on the board
USB_KBD+: J6.2, U6.4 (D+)
USB_KBD-: J6.3, U6.6 (D-)
USB_UP+: U6.3 (D2+); also elsewhere on the board
USB_UP-: U6.7 (D2-); also elsewhere on the board
VBUS_KBD: J6.1; also elsewhere on the board

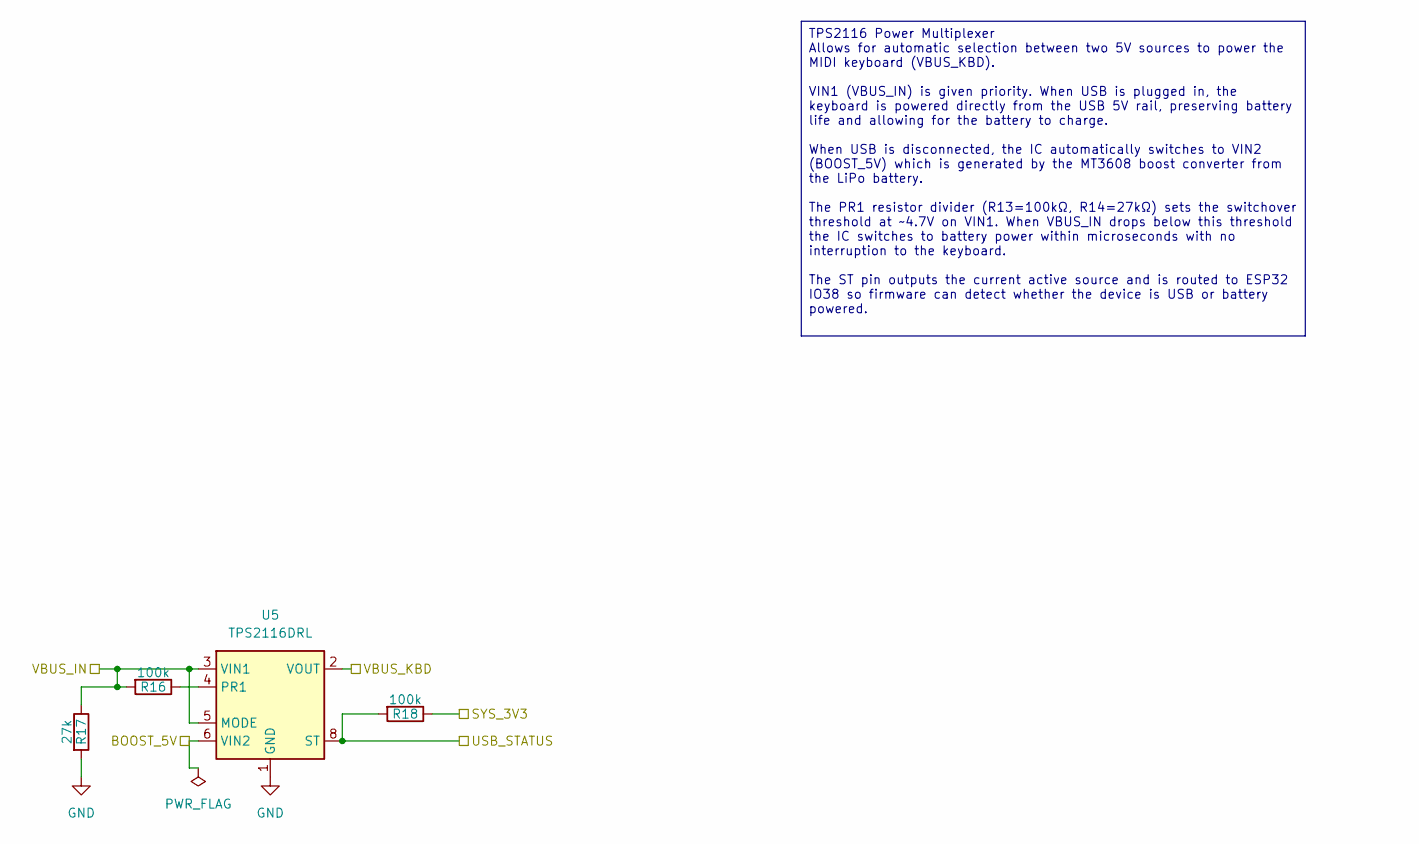
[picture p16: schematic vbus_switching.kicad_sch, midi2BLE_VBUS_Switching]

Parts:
R16, R18: 100k; R_0603_1608Metric
R17: 27k; R_0603_1608Metric
U5: TPS2116DRL; SOT-583-8

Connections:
BOOST_5V: U5.6 (VIN2); also elsewhere on the board
GND: R17.2, U5.1 (GND); also elsewhere on the board
unnamed: R16.1, U5.4 (PR1)
SYS_3V3: R18.1; also elsewhere on the board
USB_STATUS: R18.2, U5.8 (ST); also elsewhere on the board
VBUS_IN: R16.2, R17.1, U5.3 (VIN1), U5.5 (MODE); also elsewhere on the board
VBUS_KBD: U5.2 (VOUT), U5.7 (VOUT); also elsewhere on the board

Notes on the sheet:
TPS2116 Power Multiplexer Allows for automatic selection between two 5V sources to power the MIDI keyboard (VBUS_KBD). VIN1 (VBUS_IN) is given priority. When USB is plugged in, the keyboard is powered directly from the USB 5V rail, preserving battery life and allowing for the battery to charge. Whe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

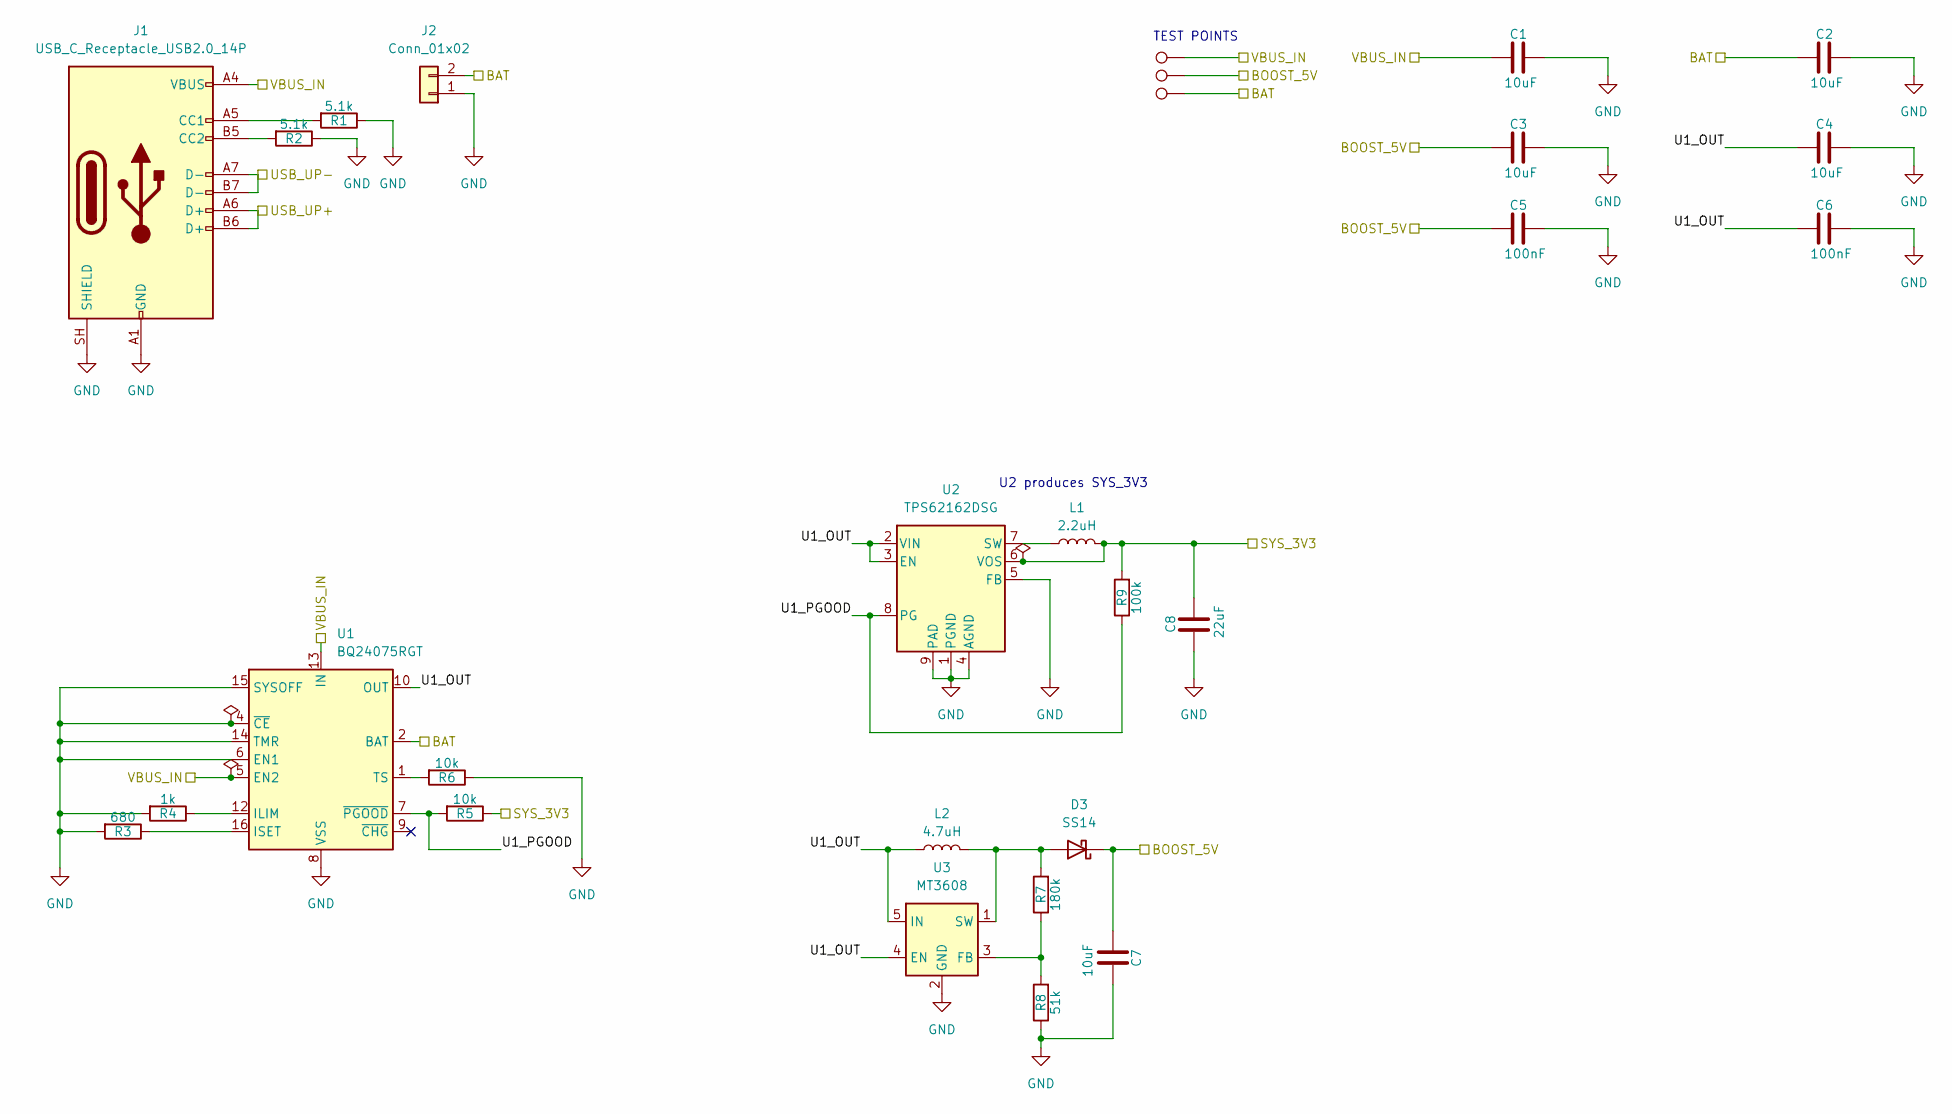
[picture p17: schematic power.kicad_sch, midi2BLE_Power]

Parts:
C1, C2, C3, C4, C7: 10uF; C_0603_1608Metric
C5, C6: 100nF; C_0603_1608Metric
C8: 22uF; C_0603_1608Metric
D3: SS14; D_SMA
J1: USB_C_Receptacle_USB2.0_14P; USB_C_Receptacle_G-Switch_GT-USB-7010ASV
J2: Conn_01x02; JST_PH_B2B-PH-K_1x02_P2.00mm_Vertical
L1: 2.2uH; L_1008_2520Metric
L2: 4.7uH; L_1008_2520Metric
R1, R2: 5.1k; R_0603_1608Metric
R3: 680; R_0603_1608Metric
R4: 1k; R_0603_1608Metric
R5, R6: 10k; R_0603_1608Metric
R7: 180k; R_0603_1608Metric
R8: 51k; R_0603_1608Metric
R9: 100k; R_0603_1608Metric
TP7, TP8, TP9: TestPoint; TestPoint_THTPad_D1.0mm_Drill0.5mm
U1: BQ24075RGT; VQFN-16-1EP_3x3mm_P0.5mm_EP1.6x1.6mm
U2: TPS62162DSG; WSON-8-1EP_2x2mm_P0.5mm_EP0.9x1.6mm_ThermalVias
U3: MT3608; SOT-23-6

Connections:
/Power/U1_OUT: C4.2, C6.2, L2.1, U1.10 (OUT), U1.11 (OUT), U2.2 (VIN), U2.3 (EN), U3.4 (EN), U3.5 (IN)
/Power/U1_PGOOD: R5.2, R9.1, U1.7 (~PGOOD), U2.8 (PG)
BAT: C2.2, J2.2, TP9.1 (1_1), U1.2 (BAT), U1.3 (BAT); also elsewhere on the board
BOOST_5V: C3.2, C5.2, C7.2, D3.1 (K), TP8.1 (1_1); also elsewhere on the board
GND: C1.1, C2.1, C3.1, C4.1, C5.1, C6.1, C7.1, C8.2, J1.A1 (GND), J1.A12 (GND), J1.B1 (GND), J1.B12 (GND), J1.SH (SHIELD), J2.1, R1.1, R2.1, R3.2, R4.2, R6.1, R8.1, U1.4 (~CE), U1.6 (EN1), U1.8 (VSS), U1.14 (TMR), U1.15 (SYSOFF), U1.17 (VSS), U2.1 (PGND), U2.4 (AGND), U2.5 (FB), U2.9 (PAD), U3.2 (GND); also elsewhere on the board
unnamed: D3.2 (A), L2.2, R7.2, U3.1 (SW)
unnamed: J1.A5 (CC1), R1.2
unnamed: J1.B5 (CC2), R2.2
unnamed: R4.1, U1.12 (ILIM)
unnamed: R3.1, U1.16 (ISET)
unnamed: R6.2, U1.1 (TS)
unnamed: L1.1, U2.7 (SW)
unnamed: R7.1, R8.2, U3.3 (FB)
SYS_3V3: C8.1, L1.2, R5.1, R9.2, U2.6 (VOS); also elsewhere on the board
USB_UP+: J1.A6 (D+), J1.B6 (D+); also elsewhere on the board
USB_UP-: J1.A7 (D-), J1.B7 (D-); also elsewhere on the board
VBUS_IN: C1.2, J1.A4 (VBUS), J1.A9 (VBUS), J1.B4 (VBUS), J1.B9 (VBUS), TP7.1 (1_1), U1.5 (EN2), U1.13 (IN); also elsewhere on the board

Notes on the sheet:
TEST POINTS
U2 produces SYS_3V3

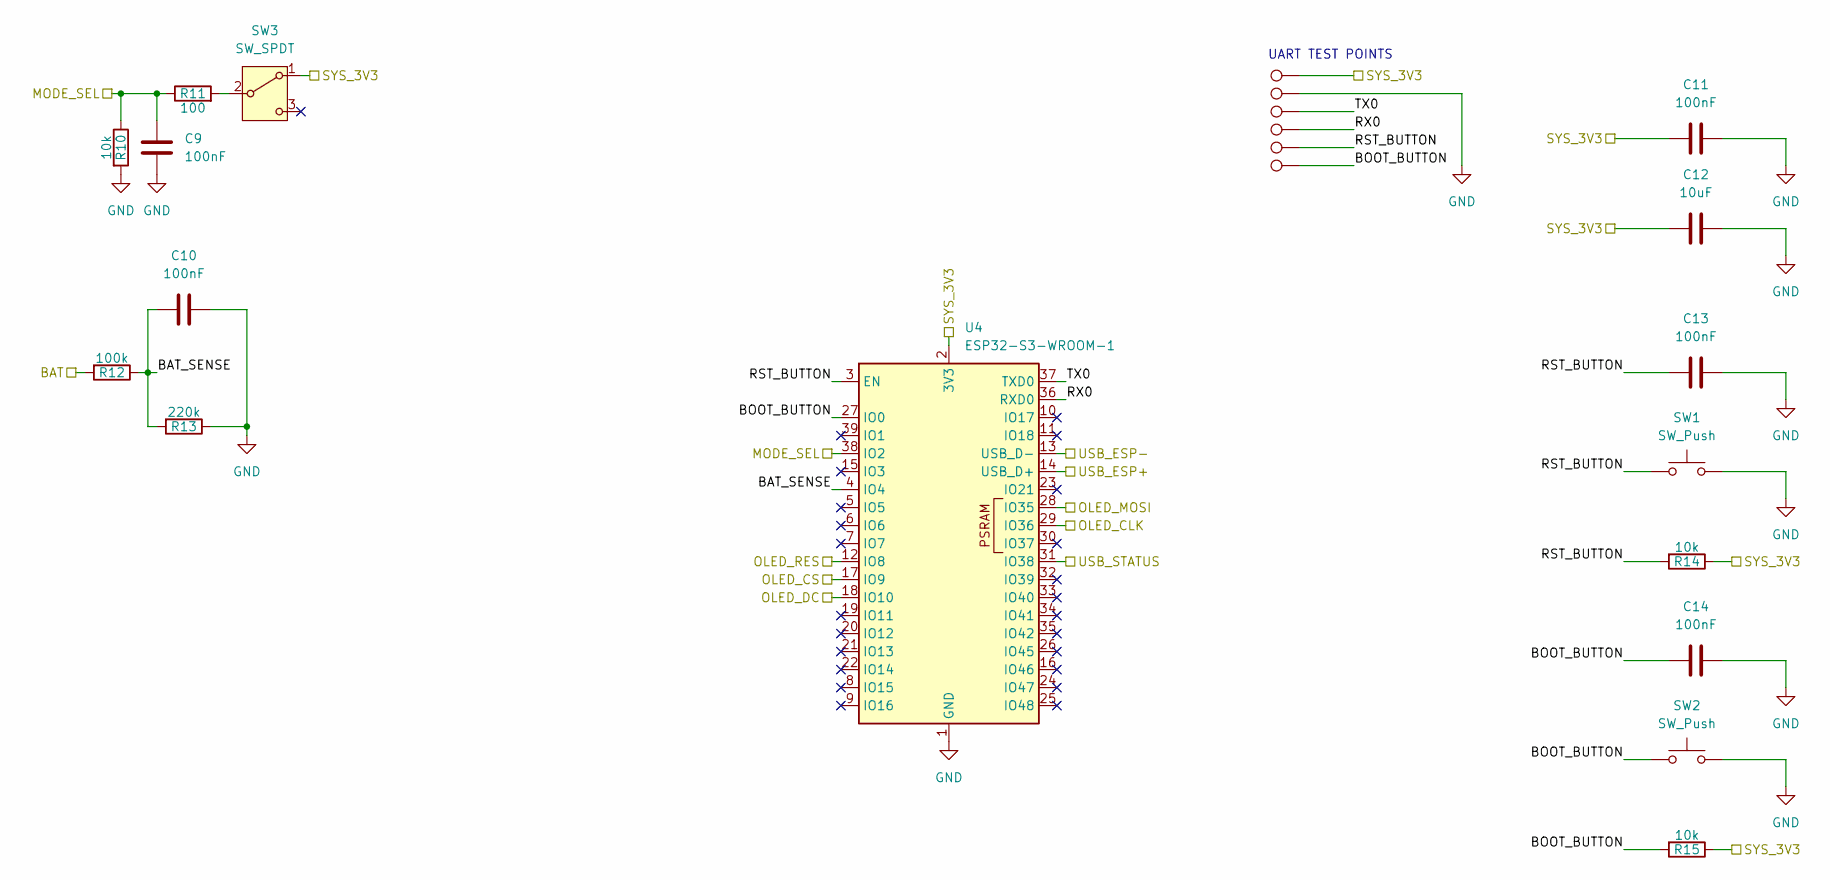
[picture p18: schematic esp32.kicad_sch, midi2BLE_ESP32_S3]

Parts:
C9, C10, C11, C13, C14: 100nF; C_0603_1608Metric
C12: 10uF; C_0603_1608Metric
R10, R14, R15: 10k; R_0603_1608Metric
R11: 100; R_0603_1608Metric
R12: 100k; R_0603_1608Metric
R13: 220k; R_0603_1608Metric
SW1, SW2: SW_Push; SW_SPST_B3U-1000P
SW3: SW_SPDT; SW_Slide_SPDT_Angled_CK_OS102011MA1Q
TP1, TP2, TP3, TP4, TP5, TP6: TestPoint; TestPoint_THTPad_D1.0mm_Drill0.5mm
U4: ESP32-S3-WROOM-1

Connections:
/ESP32_S3/BAT_SENSE: C10.1, R12.1, R13.2, U4.4 (IO4)
/ESP32_S3/BOOT_BUTTON: C14.1, R15.2, SW2.1, TP6.1 (1_1), U4.27 (IO0)
/ESP32_S3/RST_BUTTON: C13.1, R14.2, SW1.1, TP5.1 (1_1), U4.3 (EN)
/ESP32_S3/RX0: TP4.1 (1_1), U4.36 (RXD0)
/ESP32_S3/TX0: TP3.1 (1_1), U4.37 (TXD0)
BAT: R12.2; also elsewhere on the board
GND: C9.1, C10.2, C11.2, C12.2, C13.2, C14.2, R10.2, R13.1, SW1.2, SW2.2, TP2.1 (1_1), U4.1 (GND), U4.40 (GND), U4.41 (GND); also elsewhere on the board
MODE_SEL: C9.2, R10.1, R11.1, U4.38 (IO2); also elsewhere on the board
unnamed: R11.2, SW3.2 (B)
OLED_CLK: U4.29 (IO36); also elsewhere on the board
OLED_CS: U4.17 (IO9); also elsewhere on the board
OLED_DC: U4.18 (IO10); also elsewhere on the board
OLED_MOSI: U4.28 (IO35); also elsewhere on the board
OLED_RES: U4.12 (IO8); also elsewhere on the board
SYS_3V3: C11.1, C12.1, R14.1, R15.1, SW3.1 (A), TP1.1 (1_1), U4.2 (3V3); also elsewhere on the board
USB_ESP+: U4.14 (USB_D+); also elsewhere on the board
USB_ESP-: U4.13 (USB_D-); also elsewhere on the board
USB_STATUS: U4.31 (IO38); also elsewhere on the board

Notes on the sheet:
UART TEST POINTS

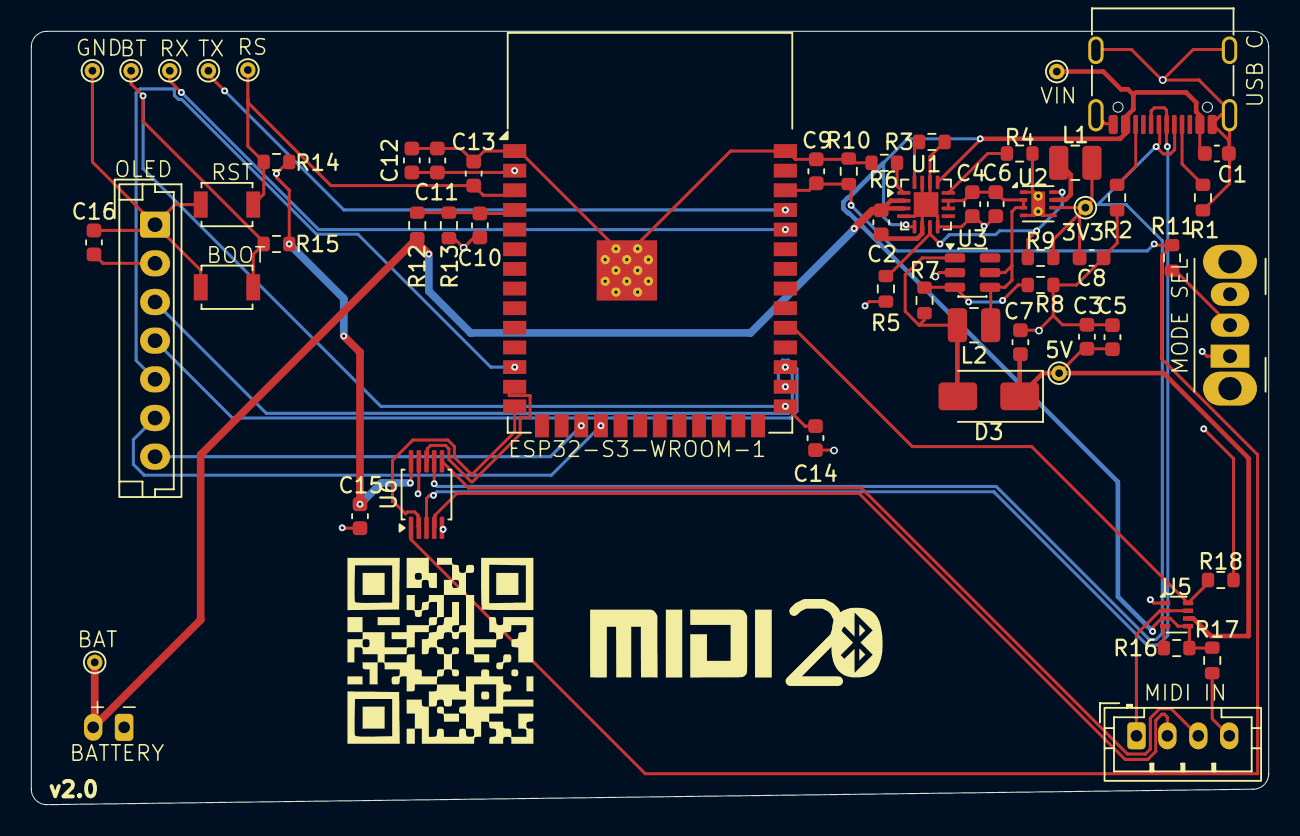
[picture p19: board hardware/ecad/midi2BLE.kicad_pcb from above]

Board: 4 copper layers, 80.0 x 50.0 mm, 59 parts (1 on the bottom side), 36 nets.

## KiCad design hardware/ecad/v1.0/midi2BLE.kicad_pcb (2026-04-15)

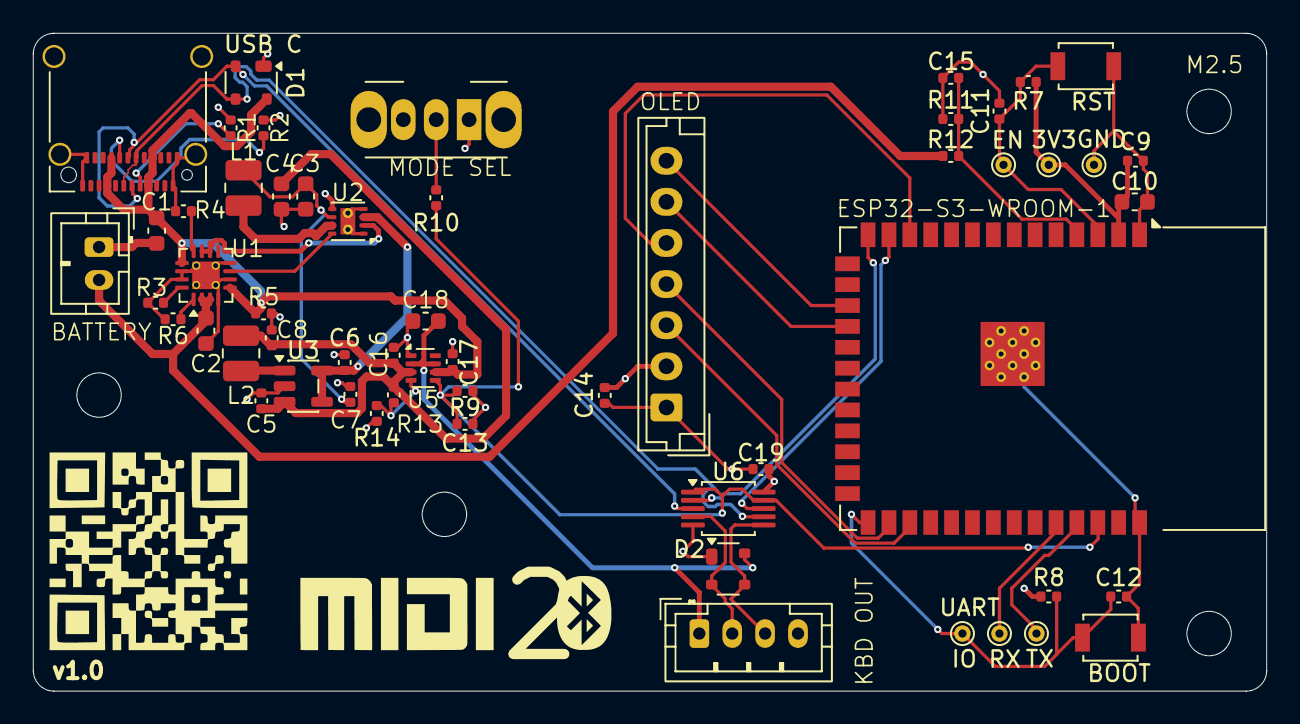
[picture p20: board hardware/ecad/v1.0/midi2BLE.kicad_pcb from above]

Board: 4 copper layers, 75.0 x 40.0 mm, 56 parts (0 on the bottom side), 36 nets.

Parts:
C1, C2, C3, C4, C10, C18: 10uF; C_0603_1608Metric
C5, C6, C7, C8, C9, C11, C12, C13, C14, C15, C16, C17, C19: 100nF; C_0402_1005Metric
D1, D2: PRTR5V0U2X; SOT-143
J1: USB_C_Receptacle; USB_C_Receptacle_Amphenol_12401610E4-2A_CircularHoles
J2: Conn_01x02; JST_PH_B2B-PH-K_1x02_P2.00mm_Vertical
J4: Conn_01x07; JST_EH_B7B-EH-A_1x07_P2.50mm_Vertical
J6: Conn_01x04; JST_PH_B4B-PH-K_1x04_P2.00mm_Vertical
L1, L2: 2.2uH; L_1008_2520Metric
R1, R2: 5.1k; C_0402_1005Metric
R3: 590; C_0402_1005Metric
R4: 1k; C_0402_1005Metric
R5, R6, R7, R8, R9: 10k; C_0402_1005Metric
R10: 100; C_0402_1005Metric
R11: 220k; C_0402_1005Metric
R12, R13, R14: 100k; C_0402_1005Metric
SW1, SW2: SW_Push; SW_SPST_B3U-1000P
SW3: SW_SPDT; SW_Slide_SPDT_Angled_CK_OS102011MA1Q
TP1, TP2, TP3, TP4, TP5, TP6: TestPoint; TestPoint_THTPad_D1.0mm_Drill0.5mm
U1: BQ24079RGTT; VQFN-16-1EP_3x3mm_P0.5mm_EP1.68x1.68mm_ThermalVias
U2: TPS62162DSG; WSON-8-1EP_2x2mm_P0.5mm_EP0.9x1.6mm_ThermalVias
U3: TLV61047DDC; SOT-23-5
U4: ESP32-S3-WROOM-1
U5: TPS2116DRL; SOT-583-8
U6: TS3USB30EDGSR; TSSOP-10_3x3mm_P0.5mm

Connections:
/ESP32_S3/BOOT_BUTTON: C12.1, R8.2, SW2.1, TP6.1 (1_1), U4.27 (IO0)
/ESP32_S3/RST_BUTTON: C11.1, R7.2, SW1.1, TP5.1 (1_1), U4.3 (EN)
/ESP32_S3/RX0: TP4.1 (1_1), U4.36 (RXD0)
/ESP32_S3/TX0: TP3.1 (1_1), U4.37 (TXD0)
/Power/J1 CC1 - R1 P1: J1.A5 (CC1), R1.2
/Power/J1 CC2 - R2 P1: J1.B5 (CC2), R2.2
/Power/U1 ILIM - R4 P1: R4.2, U1.12 (ILIM)
/Power/U1 ISET - R3 P1: R3.2, U1.16 (ISET)
/Power/U1 OUT_2 - U2 VIN: U1.10 (OUT), U1.11 (OUT@2), U2.2 (VIN)
/Power/U1 TS - R6 P1: R6.2, U1.1 (TS)
/Power/U2 EN - U3 VIN: C6.2, U2.3 (EN), U3.4 (EN), U3.5 (VIN)
/Power/U2 FB - C3 P1: C3.2, C7.2, L1.2, U2.6 (VOS)
/Power/U2 PG - R7 P2: U1.7 (~PGOOD), U2.8 (PG)
/Power/U2 SW - L1 P1: L1.1, U2.7 (SW)
BAT: C2.2, J2.2, R12.2, U1.2 (BAT), U1.3 (BAT@2)
BAT_SENSE: C15.1, R11.2, R12.1, U4.4 (IO4)
BOOST_5V: C4.2, C5.2, C8.2, C16.1, L2.2, R13.2, U3.3 (FB), U5.3 (VIN1)
GND: C1.1, C2.1, C3.1, C4.1, C5.1, C6.1, C7.1, C8.1, C9.2, C10.2, C11.2, C12.2, C13.1, C14.2, C15.2, C16.2, C17.2, C18.2, C19.2, D1.1 (GND), D2.1 (GND), J1.A1 (GND), J1.A12 (GND), J1.B1 (GND), J1.B12 (GND), J1.SH (SHIELD), J2.1, J4.1, J6.4, R1.1, R2.1, R3.1, R4.1, R5.1, R6.1, R9.2, R11.1, R14.2, SW1.2, SW2.2, TP2.1 (1_1), U1.4 (~CE), U1.6 (EN1), U1.8 (VSS), U1.14 (TMR), U1.15 (ITERM), U1.17 (PAD), U2.1 (PGND), U2.4 (AGND), U2.9 (PAD), U3.2 (GND), U4.1 (GND), U4.40 (GND), U4.41 (GND), U5.1 (GND), U6.5 (GND)
MODE_SEL: C13.2, R9.1, R10.1, U4.38 (IO2), U5.5 (MODE), U6.1 (S), U6.9 (~OE)
unnamed: R10.2, SW3.2 (B)
unnamed: L2.1, U3.1 (SW)
unnamed: R13.1, R14.1, U5.4 (PR1)
OLED_CLK: J4.3, U4.29 (IO36)
OLED_CS: J4.7, U4.17 (IO9)
OLED_DC: J4.6, U4.18 (IO10)
OLED_MOSI: J4.4, U4.28 (IO35)
OLED_RES: J4.5, U4.12 (IO8)
SYS_3V3: C9.1, C10.1, C14.1, C19.1, J4.2, R7.1, R8.1, SW3.1 (A), TP1.1 (1_1), U2.5 (FB), U4.2 (3V3), U6.10 (VCC)
USB_ESP+: U4.14 (USB_D+), U6.2 (D1+)
USB_ESP-: U4.13 (USB_D-), U6.8 (D1-)
USB_KBD+: D2.2 (I/O1), J6.2, U6.4 (D+)
USB_KBD-: D2.3 (I/O2), J6.3, U6.6 (D-)
USB_UP+: D1.2 (I/O1), J1.A6 (D+), J1.B6 (D+), U6.3 (D2+)
USB_UP-: D1.3 (I/O2), J1.A7 (D-), J1.B7 (D-), U6.7 (D2-)
VBUS_IN: C1.2, C17.1, D1.4 (VCC), J1.A4 (VBUS), J1.A9 (VBUS), J1.B4 (VBUS), J1.B9 (VBUS), R5.2, U1.5 (EN2), U1.13 (IN), U5.6 (VIN2)
VBUS_KBD: C18.1, D2.4 (VCC), J6.1, U5.2 (VOUT), U5.7 (VOUT)

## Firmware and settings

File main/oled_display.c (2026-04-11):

/*
 * SSD1306 128×64 OLED display driver with status screen composition.
 *
 * Uses SPI (CLK/MOSI/DC/CS/RES).  The framebuffer is 8 pages × 128 columns
 * (1024 bytes).  Text is rendered using a built-in 5×7 bitmap font at 6 px per
 * character (5 px glyph + 1 px gap), giving 21 characters per line and 8 lines.
 *
 * NOTE: Some 1.3" modules labelled "SSD1306" actually use an SH1106 controller.
 * The SH1106 has a 132-column internal RAM with a 2-column offset and does not
 * support horizontal addressing mode.  If the display shows garbage or nothing,
 * switch to SH1106 page-mode writes.
 */

#include "oled_display.h"

#include <string.h>
#include <stdio.h>
#include "driver/spi_master.h"
#include "driver/gpio.h"
#include "esp_log.h"
#include "freertos/FreeRTOS.h"
#include "freertos/task.h"

#define TAG "OLED"

// ---------------------------------------------------------------------------
// Hardware constants
// ---------------------------------------------------------------------------

#define SSD1306_WIDTH   128
#define SSD1306_HEIGHT  64
#define SSD1306_PAGES   8    // HEIGHT / 8

#define FONT_W  5   // glyph pixel width
#define FONT_H  7   // glyph pixel height (fits in one 8-px page)
#define CHAR_W  6   // advance width (glyph + 1 px gap)
#define CHARS_PER_LINE  (SSD1306_WIDTH / CHAR_W)  // 21

// ---------------------------------------------------------------------------
// 5×7 bitmap font, ASCII 0x20–0x7E
// Each entry is 5 bytes — one byte per column, bit 0 = top pixel.
// Data compatible with the Adafruit GFX default font (glcdfont.c).
// ---------------------------------------------------------------------------

static const uint8_t s_font[95][5] = {
    {0x00,0x00,0x00,0x00,0x00}, // 0x20 ' '
    {0x00,0x00,0x5F,0x00,0x00}, // 0x21 '!'
    {0x00,0x07,0x00,0x07,0x00}, // 0x22 '"'
    {0x14,0x7F,0x14,0x7F,0x14}, // 0x23 '#'
    {0x24,0x2A,0x7F,0x2A,0x12}, // 0x24 '$'
    {0x23,0x13,0x08,0x64,0x62}, // 0x25 '%'
    {0x36,0x49,0x55,0x22,0x50}, // 0x26 '&'
    {0x00,0x05,0x03,0x00,0x00}, // 0x27 '\''
    {0x00,0x1C,0x22,0x41,0x00}, // 0x28 '('
    {0x00,0x41,0x22,0x1C,0x00}, // 0x29 ')'
    {0x14,0x08,0x3E,0x08,0x14}, // 0x2A '*'
    {0x08,0x08,0x3E,0x08,0x08}, // 0x2B '+'
    {0x00,0x50,0x30,0x00,0x00}, // 0x2C ','
    {0x08,0x08,0x08,0x08,0x08}, // 0x2D '-'
    {0x00,0x60,0x60,0x00,0x00}, // 0x2E '.'
    {0x20,0x10,0x08,0x04,0x02}, // 0x2F '/'
    {0x3E,0x51,0x49,0x45,0x3E}, // 0x30 '0'
    {0x00,0x42,0x7F,0x40,0x00}, // 0x31 '1'
    {0x42,0x61,0x51,0x49,0x46}, // 0x32 '2'
    {0x21,0x41,0x45,0x4B,0x31}, // 0x33 '3'
    {0x18,0x14,0x12,0x7F,0x10}, // 0x34 '4'
    {0x27,0x45,0x45,0x45,0x39}, // 0x35 '5'
    {0x3C,0x4A,0x49,0x49,0x30}, // 0x36 '6'
    {0x01,0x71,0x09,0x05,0x03}, // 0x37 '7'
    {0x36,0x49,0x49,0x49,0x36}, // 0x38 '8'
    {0x06,0x49,0x49,0x29,0x1E}, // 0x39 '9'
    {0x00,0x36,0x36,0x00,0x00}, // 0x3A ':'
    {0x00,0x56,0x36,0x00,0x00}, // 0x3B ';'
    {0x08,0x14,0x22,0x41,0x00}, // 0x3C '<'
    {0x14,0x14,0x14,0x14,0x14}, // 0x3D '='
    {0x00,0x41,0x22,0x14,0x08}, // 0x3E '>'
    {0x02,0x01,0x51,0x09,0x06}, // 0x3F '?'
    {0x32,0x49,0x79,0x41,0x3E}, // 0x40 '@'
    {0x7E,0x11,0x11,0x11,0x7E}, // 0x41 'A'
    {0x7F,0x49,0x49,0x49,0x36}, // 0x42 'B'
    {0x3E,0x41,0x41,0x41,0x22}, // 0x43 'C'
    {0x7F,0x41,0x41,0x22,0x1C}, // 0x44 'D'
    {0x7F,0x49,0x49,0x49,0x41}, // 0x45 'E'
    {0x7F,0x09,0x09,0x09,0x01}, // 0x46 'F'
    {0x3E,0x41,0x49,0x49,0x7A}, // 0x47 'G'
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
};

// ---------------------------------------------------------------------------
// Framebuffer & hardware handles
// ---------------------------------------------------------------------------

static uint8_t s_fb[SSD1306_PAGES][SSD1306_WIDTH];  // [page][column]

static spi_device_handle_t s_spi = NULL;
static bool s_ok = false;  // set true only if init succeeded

// ---------------------------------------------------------------------------
// Display state (written from any task; read in oled_update)
// ---------------------------------------------------------------------------

static device_mode_t s_mode        = MODE_WIRELESS;
static bool          s_ble_conn    = false;
static bool          s_usb_conn    = false;
static bool          s_midi_active = false;
static uint8_t       s_bat_pct     = 0;
static char          s_usb_name[44] = {0};  // up to 2 lines of 21 chars

// ---------------------------------------------------------------------------
// SSD1306 low-level helpers
// ---------------------------------------------------------------------------

static void spi_send(const uint8_t *data, size_t len, bool is_data)
{
    gpio_set_level(OLED_DC, is_data ? 1 : 0);
    spi_transaction_t t = {
        .length   = len * 8,
        .tx_buffer = data,
    };
    spi_device_polling_transmit(s_spi, &t);
}

static void ssd1306_send_cmds(const uint8_t *cmds, size_t len)
{
    spi_send(cmds, len, false);
}

static void ssd1306_flush(void)
{
    // SH1106 uses page-addressing only, with a 2-column internal RAM offset.
    // Writing page-by-page works on both SH1106 and SSD1306.
    // If display is shifted 2 px left, change OLED_COL_OFFSET to 0.
    #define OLED_COL_OFFSET 2
    for (int page = 0; page < SSD1306_PAGES; page++) {
        uint8_t cmds[] = {
            0xB0 | page,                          // set page
            0x00 | (OLED_COL_OFFSET & 0x0F),      // column low nibble
            0x10 | ((OLED_COL_OFFSET >> 4) & 0x0F), // column high nibble
        };
        ssd1306_send_cmds(cmds, sizeof(cmds));
        spi_send(s_fb[page], SSD1306_WIDTH, true);
    }
    #undef OLED_COL_OFFSET
}

// ---------------------------------------------------------------------------
// Framebuffer drawing primitives
// ---------------------------------------------------------------------------

static void fb_clear(void)
{
    memset(s_fb, 0, sizeof(s_fb));
}

/** Draw one glyph at pixel column x, text page (0–7). */
static void fb_char(int page, int x, char c)
{
    if (c < 0x20 || c > 0x7E) c = ' ';
    if (page < 0 || page >= SSD1306_PAGES) return;
    const uint8_t *g = s_font[(uint8_t)c - 0x20];
    for (int col = 0; col < FONT_W; col++) {
        if (x + col >= SSD1306_WIDTH) break;
        s_fb[page][x + col] = g[col];
    }
}

/** Draw a NUL-terminated string starting at pixel column x on text page. */
static void fb_str(int page, int x, const char *str)
{
    while (*str && x < SSD1306_WIDTH) {
        fb_char(page, x, *str++);
        x += CHAR_W;
    }
}

/** Draw a string horizontally centred on page. */
static void fb_str_center(int page, const char *str)
{
    int len = (int)strlen(str);
    int x   = (SSD1306_WIDTH - len * CHAR_W) / 2;
    if (x < 0) x = 0;
    fb_str(page, x, str);
}
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

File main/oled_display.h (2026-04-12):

#pragma once

#include <stdint.h>
#include <stdbool.h>
#include "mode_manager.h"
#include "driver/gpio.h"

// SPI pins — adjust to match PCB once schematic is finalised
#define OLED_CLK   GPIO_NUM_36
#define OLED_MOSI  GPIO_NUM_35
#define OLED_DC    GPIO_NUM_10   // Data/Command select
#define OLED_CS    GPIO_NUM_9    // Chip select
#define OLED_RES   GPIO_NUM_8    // Hardware reset

/**
 * Initialise the SSD1306 over I2C and clear the display.
 * Safe to call even if no display is physically connected — subsequent calls
 * will silently no-op if initialisation fails.
 */
void oled_init(void);

// ---- State setters (callable from any task) ---------------------------------

void oled_set_mode(device_mode_t mode);
void oled_set_ble_connected(bool connected);

/**
 * @param connected   true when a USB MIDI device is enumerated
 * @param device_name Product string from the USB descriptor, or "" if unavailable.
 *                    Truncated to 21 characters on screen.
 */
void oled_set_usb_connected(bool connected, const char *device_name);

/** Call each time a MIDI packet is received — clears automatically after redraw. */
void oled_set_midi_active(bool active);

void oled_set_battery(uint8_t percent);

// ---- Display actions --------------------------------------------------------

/**
 * Show "MODE CHANGED / RESTARTING..." for ~2 s.
 * Intended to be called just before esp_restart().
 */
void oled_show_mode_change(void);

/**
 * Redraw the full screen from current state and push to hardware.
 * Call at ~1 Hz from the OLED update task.
 */
void oled_update(void);

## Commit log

2026-04-10 ESP32 works as a UBS pass thorugh to the serial monitor now!
2026-04-10 Updated firmware to include builtin panic button in case keyboard dies
2026-04-11 Add OLED display, mode switch, and battery monitor
    - New modules: mode_manager, oled_display, battery
    - Mode switch on GPIO2 reads at boot; NVS detects changes and restarts cleanly
    - SH1106 SPI OLED driver with 5x7 font, page-by-page writes, 180° rotation
    - Status screens for WIRELESS and PASSTHROUGH modes
    - USB device name built from manufacturer + product descriptor strings
    - Battery ADC on GPIO4 with voltage divider; bar and percentage on display
    - NVS init moved to app_main; PASSTHROUGH skips BLE and USB host entirely
    [battery.c, battery.h, mode_manager.c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]
2026-04-11 Add MCAD enclosure v1 and update docs
    - Enclosure body v1 in Fusion 360 — USB-B cutout, fitment verified against keyboard
    - Updated MCAD README and changelog
    [midi2BLE.f3d]
2026-04-11 Initial KiCad project import
    [midi2BLE.kicad_pcb, midi2BLE.kicad_sch]
2026-04-11 Finsihed power schematic, but needs work... pcb has lots of errors still
    [battery_sense.kicad_sch, esp32.kicad_sch, midi2BLE.kicad_pcb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]
2026-04-12 Updated code for battery readout
2026-04-12 Reassigned OLED SPI pins away from Octal flash GPIOs (GPIO11/12) and move BAT_SENSE to ADC1 to avoid BLE/ADC2 conflict
    [oled_display.h]
2026-04-12 Power schematic finished, top level schematic editied to swap from I2c to SPI instead
    [midi2BLE.kicad_pcb, midi2BLE.kicad_sch, power.kicad_sch]
2026-04-13 finsihed 6/7 sheets, usb_data needs work. Some warnings to be dealt with aswell but no hard errors.
    [battery_sense.kicad_sch, esp32.kicad_sch, midi2BLE.kicad_pcb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]
2026-04-14 Updated schematics to get rid of errors and warnings
    [esp32.kicad_sch, midi2BLE.kicad_sch, power.kicad_sch]
2026-04-14 feat: complete schematic design for midi2BLE v1
    - Add 7-sheet hierarchical schematic covering full system architecture
    - Power sheet: BQ24079RGTT charger, TPS62162DSG 3.3V buck, TLV61047DDC
    5V boost, PRTR5V0U2X ESD protection, USB-C receptacle with CC resistors
    - ESP32-S3 sheet: WROOM-1-N8R2 module, UART header, boot/reset buttons,
    MODE_SEL debounce circuit, BAT_SENSE ADC input
    - OLED UI sheet: SPI SSD1306 connector (GPIO35/36/10/9/8)
    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
    [midi2BLE.kicad_pcb, midi2BLE.kicad_sch, power.kicad_sch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]
2026-04-14 Updated schematics and added printed pdf
    [battery_sense.kicad_sch, esp32.kicad_sch, midi2BLE.kicad_pcb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]
2026-04-14 docs(hardware): update ecad README to reflect completed schematic and PCB — PCB IS DONE!!!
    [esp32.kicad_sch, midi2BLE.kicad_pcb, midi2BLE.kicad_sch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]
2026-04-15 Updated KiCad projectm and pcb, added in BOM
    [midi2BLE.kicad_pcb, midi2BLE_BOM.csv]
2026-05-01 Fix link case in README.md
2026-05-15 fix: resolve fatal power and USB switching errors
    Replace TLV61047 boost converter with MT3608; add SS14 catch diode, 4.7µH inductor, and correct FB divider (180kΩ/51kΩ) for 5V output
    Fix TPS62162DSG EN circular dependency; connect directly to U1_OUT
    Fix TPS62162DSG FB pin; disconnect from SYS_3V3 and tie to GND
    Fix TPS2116 power mux; remove series resistor on VIN1, add correct PR1 divider (100kΩ/27kΩ), tie MODE to VIN1 for priority mode
    Fix TS3USB30E OE pin; tie directly to GND to keep switch always enabled
    Add PGOOD pull-up resistor (10kΩ) to SYS_3V3 on BQ24079
    Change ISET resistor from 590Ω to 680Ω for 1.3A charge current
    Remove unnecessary R5 (10kΩ VBUS_IN to GND bleed resistor)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
    [esp32.kicad_sch, midi2BLE.kicad_sch, oled_ui.kicad_sch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]
2026-05-16 Fixed minor errors and smaller issues withing schematics, moved v1 pcb and specific projet artifacts to archive. Produced PDF of full schematic
    [battery_sense.kicad_sch, esp32.kicad_sch, midi2BLE.kicad_pcb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]
2026-05-26 Fixed minor errors and smaller issues withing schematics, moved v1 pcb and specific projet artifacts to archive. Updated changelog and finsihed pcb fopr version 2
    [esp32.kicad_sch, midi2BLE.kicad_pcb, power.kicad_sch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]

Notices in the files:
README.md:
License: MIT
